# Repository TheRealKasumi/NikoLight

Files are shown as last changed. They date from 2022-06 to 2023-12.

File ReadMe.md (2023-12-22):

# NikoLight






## Disclaimer for Hardware 2.2

Currently I am rewriting the firmware from scratch including many improvements and new features.
The release was planned for Christmas 2023.
Even when many parts of the new firmware are already working, I am currently a little time limited and will not be able to finish it in time.
Instead, I added experimental support for the v2.2 hardware to the current firmware.
This does not come with all the new software and hardware features but it allows you to use the new (2.2) NikoLight boards with a significantly higher power output and the overall improved hardware.

The hardware version can be adjusted in the [SystemConfiguration.h](./mcu/include/configuration/SystemConfiguration.h).
Again, keep in mind that this experimental and there might be some hidden issues.

## Introduction

NikoLight is an open source ambient light that you can build yourself.
The project is primarily aimed at people who are not looking for a ready-made solution and prefer to tinker, modify, extend and work on it as a community.
As the name suggests, the project was started primarily for Tesla vehicles.
The focus is on the Model 3 and Model Y.
However, it can also be used for other cars with some small modifications.

With NikoLight you can control up to 8 zones with a variable number of WS2812-type LEDs.
For example, the 4 doors, the center console, the footwell lights and a light bar under the dashboard.
In total, several hundred LEDs can be controlled individually.

Since there should be an easy way to control all these LEDs, there are many different effects for each zone.
These can display a simple color, color gradients or even animations in the individual zones.
Since the controller has a motion sensor, some effects are even interactive.
The effects are expandable in the future and can be adapted to your wishes over time.
Even fully customized animation are possible.
You can create these on your computer and play them back in the car.

NikoLight can be easily integrated into your Tesla (and other cars).
There is a sensor that can be connected to the lighting around the footwell.
This way, NikoLight switches on and off automatically when you open or lock the car.
It is also possible to regulate the brightness together with the factory-installed lights or via the display.
The controller is also expandable and could support additional hardware in the future.
For example, there could be a CAN adapter to get more information from the vehicle.
How relevant these extensions will be, depends a little bit on the community and the support I will receive.

Once built and installed, NikoLight can be configured via a browser-based UI.
When starting the controller, a Wi-Fi hotspot is created, which you can connect to with any device.
The user interface can be accessed via a normal browser thanks to the integrated web server.
The project is therefore mostly platform-independent.

**Here is a short summary of the currently most interesting features:**

- Individual control of each LED installed in the car
- Hundreds of LEDs are possible
- Compatible with all WS2812-type LEDs (and LEDs with the same protocol)
- Fiber cables, light bars and normal LED strips are supported
- Up to 8 individual zones
- Currently 18 different effects that can be selected and further customized for each zone
- Browser based user interface
- Switching on/off as well as dynamic brightness via the existing lighting in the footwell
- Rotation and acceleration sensors
- Interactive effects
- Light shows
- Fully customized animations can be created on your PC (playback of fseq 1.0 files from [xLights](https://xlights.org/))
- OTA (wireless) updates
- Hardware is upgradeable via extensions in the future

## Some Videos and Pictures

NikoLight Demo 2 (https://www.youtube.com/watch?v=_N5h1IViB-E)

(click to watch on YouTube)

NikoLight Demo 1 (https://www.youtube.com/watch?v=bwzbVkCsNws)

(click to watch on YouTube)

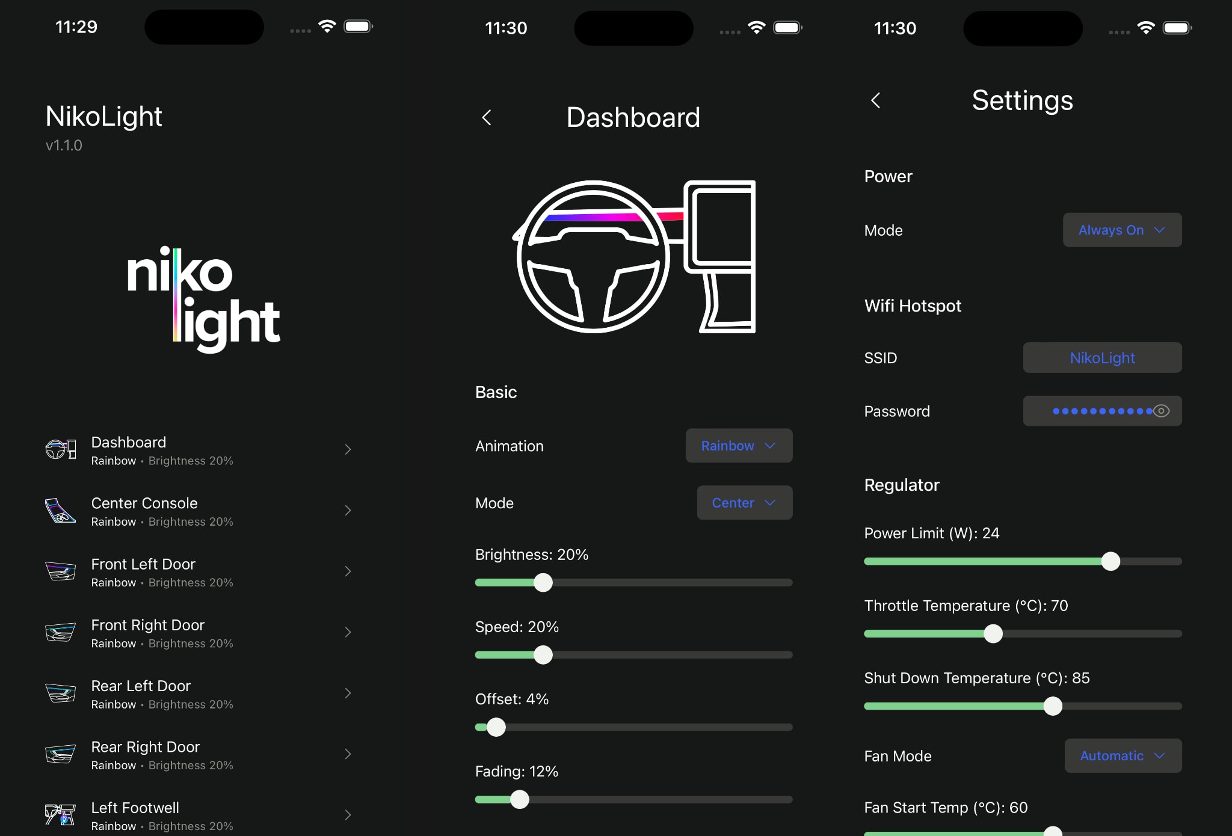
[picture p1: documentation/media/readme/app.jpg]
App


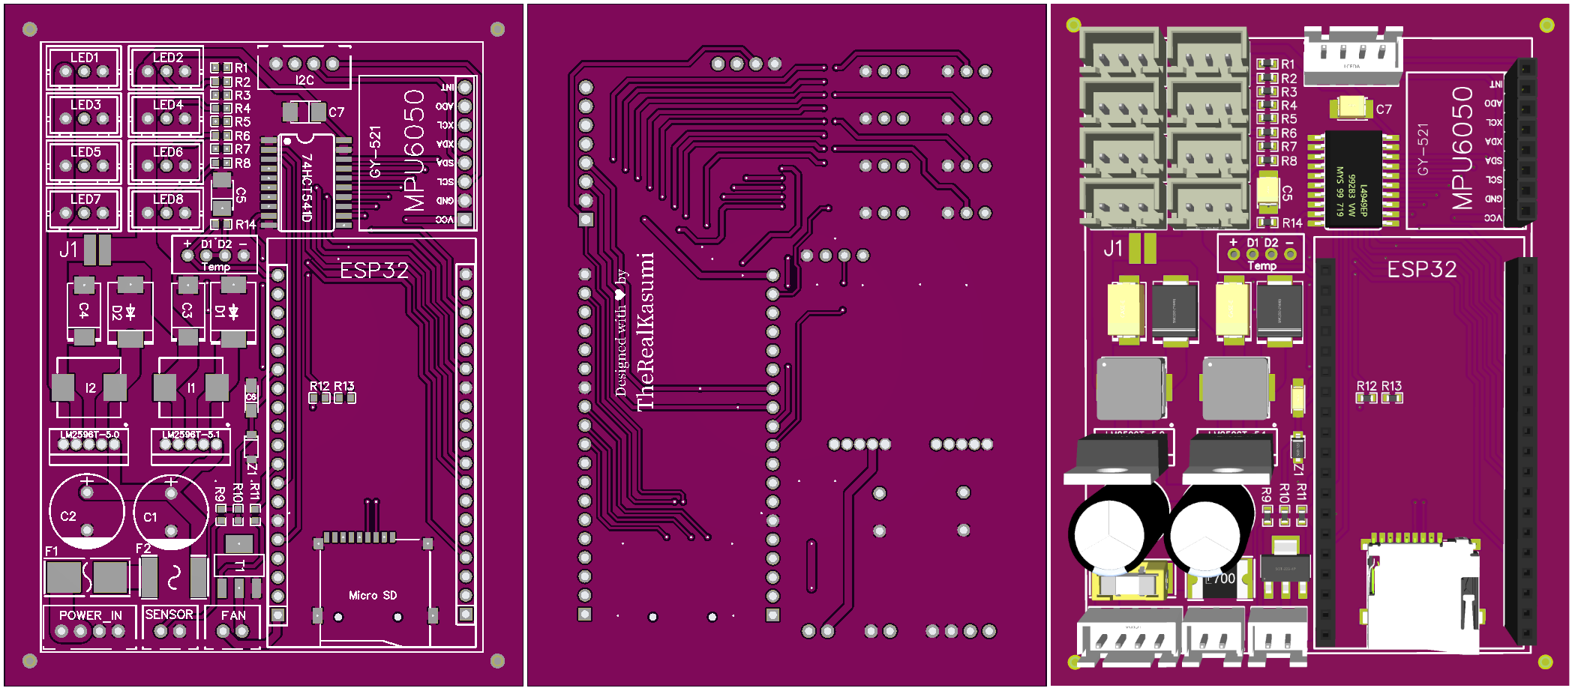
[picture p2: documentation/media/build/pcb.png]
PCB


## Planning

It is recommended to read the [planning](documentation/planning.md) document before you start the project.
There are some important considerations and decisions you have to make first.
This will save you some trouble and makes it easier to buy the right parts.

## Part List

A list of required and optional parts can be found [here](documentation/part-list.md).

## Build Guide

The build guide can be found [here](documentation/build.md).

## One Request

A lot of our time, effort and money went into this project.
Nevertheless, we share it publicly with you.
You can use it for free, modify it and even earn a coffee by building the parts for other people as long as you are a private person without commercial intentions.
But please **don't steal** our work, be a little **respectful** and **give credits**.
That said, I hope you have a lot of fun and great experience with NikoLight!
Thank you💖!

## Contributors

<table>
	<tbody>
		<tr>
			<td align="center" valign="top" width="200px">
        <br />
				<a href="https://github.com/TheRealKasumi">
					TheRealKasumi
					<br />
					<b>TheRealKasumi</b>
				</a>
				<hr />
				<p style="text-align: left">
					<a href="https://github.com/TheRealKasumi/NikoLight/issues?q=author%3ATheRealKasumi">🐛 bug</a><br />
					<a href="https://github.com/TheRealKasumi/NikoLight/commits?author=TheRealKasumi">💻 code</a><br />
					🖋 content<br />
					<a href="https://github.com/TheRealKasumi/NikoLight/commits?author=TheRealKasumi">📖 doc</a><br />
					<a href="https://github.com/TheRealKasumi/NikoLight/tree/main/ui">🎨 design</a><br />
					💡 example<br />
					🤔 ideas<br />
					<a href="https://github.com/TheRealKasumi/NikoLight/tree/main/.github">🚇 infra</a><br />
					<a href="https://github.com/TheRealKasumi/NikoLight/commits?author=TheRealKasumi">🚧 maintenance</a><br />
					<a href="https://github.com/TheRealKasumi/NikoLight">🧑‍🏫 mentoring</a><br />
					<a href="https://github.com/TheRealKasumi/NikoLight/commits?author=TheRealKasumi">📦 platform</a><br />
					<a href="https://github.com/TheRealKasumi/NikoLight">🔌 plugin</a><br />
					📆 projectManagement<br />
					📣 promotion<br />
					💬 question<br />
					🔬 research<br />
					<a href="https://github.com/TheRealKasumi/NikoLight/pulls?q=is%3Apr+reviewed-by%3ATheRealKasumi">👀 review</a><br />
					🛡️ security<br />
					<a href="https://github.com/TheRealKasumi/NikoLight">🔧 tool</a><br />
					<a href="https://github.com/TheRealKasumi/NikoLight/commits?author=TheRealKasumi">⚠️ test</a><br />
					<a href="https://github.com/TheRealKasumi/NikoLight/blob/main/documentation/build.md">✅ tutorial</a><br />
					<a href="https://www.youtube.com/watch?v=_N5h1IViB-E">📹 video</a><br />
				</p>
			</td>
			<td align="center" valign="top" width="200px">
        <br />
				<a href="https://github.com/danielbayerlein">
					danielbayerlein
					<br />
					<b>danielbayerlein</b>
				</a>
				<hr />
				<p style="text-align: left">
					<a href="https://github.com/TheRealKasumi/NikoLight/issues?q=author%3Adanielbayerlein">🐛 bug</a><br />
					<a href="https://github.com/TheRealKasumi/NikoLight/commits?author=danielbayerlein">💻 code</a><br />
					<a href="https://github.com/TheRealKasumi/NikoLight/tree/main/ui">🎨 design</a><br />
					🤔 ideas<br />
					<a href="https://github.com/TheRealKasumi/NikoLight/tree/main/.github">🚇 infra</a><br />
					<a href="https://github.com/TheRealKasumi/NikoLight/commits?author=danielbayerlein">🚧 maintenance</a><br />
					📆 projectManagement<br />
					💬 question<br />
					<a href="https://github.com/TheRealKasumi/NikoLight/pulls?q=is%3Apr+reviewed-by%3Adanielbayerlein">👀 review</a
					><br />
					<a href="https://github.com/TheRealKasumi/NikoLight/tree/main/ui/public/locales">🌍 translation</a><br />
					<a href="https://github.com/TheRealKasumi/NikoLight/commits?author=danielbayerlein">⚠️ test</a><br />
				</p>
			</td>
			<td align="center" valign="top" width="200px">
        <br />
				<a href="https://github.com/JakobLichterfeld">
					JakobLichterfeld
					<br />
					<b>JakobLichterfeld</b>
				</a>
				<hr />
				<p style="text-align: left">
					<a href="https://github.com/TheRealKasumi/NikoLight/issues?q=author%3AJakobLichterfeld">🐛 bug</a><br />
					<a href="https://github.com/TheRealKasumi/NikoLight/commits?author=JakobLichterfeld">💻 code</a><br />
					<a href="https://github.com/TheRealKasumi/NikoLight/commits?author=JakobLichterfeld">📖 doc</a><br />
					🤔 ideas<br />
					<a href="https://github.com/TheRealKasumi/NikoLight/tree/main/.github">🚇 infra</a><br />
					<a href="https://github.com/TheRealKasumi/NikoLight/commits?author=JakobLichterfeld">🚧 maintenance</a><br />
					<a href="https://github.com/TheRealKasumi/NikoLight">🧑‍🏫 mentoring</a><br />
					📆 projectManagement<br />
					💬 question<br />
					<a href="https://github.com/TheRealKasumi/NikoLight/pulls?q=is%3Apr+reviewed-by%3AJakobLichterfeld">👀 review</a><br />
					<a href="https://github.com/TheRealKasumi/NikoLight/commits?author=JakobLichterfeld">⚠️ test</a><br />
					<a href="https://github.com/TheRealKasumi/NikoLight/blob/main/documentation/build.md">✅ tutorial</a><br />
				</p>
			</td>
			<td align="center" valign="top" width="200px">
        <br />
				<a href="https://github.com/heyitsmarlon">
					heyitsmarlon
					<br />
					<b>heyitsmarlon</b>
				</a>
				<hr />
				<p style="text-align: left">
					<a href="https://github.com/TheRealKasumi/NikoLight/commit/0f9c097bd0b3cda26543b43a7343aa3b4d4c56f0">📖 doc</a><br />
				</p>
			</td>
			<td align="center" valign="top" width="200px">
        <br />
				<a href="https://github.com/MathiasSeifert">
					MathiasSeifert
					<br />
					<b>MathiasSeifert</b>
				</a>
				<hr />
				<p style="text-align: left">
					<a href="https://github.com/TheRealKasumi/NikoLight/commits?author=MathiasSeifert">📖 doc</a><br />
				</p>
			</td>
      </tr>
      <tr>
			<td align="center" valign="top" width="200px">
        <br />
				<a href="https://github.com/PhilippDenn">
					PhilippDenn
					<br />
					<b>PhilippDenn</b>
				</a>
				<hr />
				<p style="text-align: left">
					<a href="https://github.com/TheRealKasumi/NikoLight/issues?q=author%3APhilippDenn">🐛 bug</a><br />
					🤔 ideas<br />
				</p>
			</td>
			<td align="center" valign="top" width="200px">
        <br />
				<a href="https://github.com/rgrae81">
					rgrae81
					<br />
					<b>rgrae81</b>
				</a>
				<hr />
				<p style="text-align: left">
					<a href="https://github.com/TheRealKasumi/NikoLight/tree/main/model">🎨 design</a><br />
				</p>
			</td>
      <td align="center" valign="top" width="200px"></td>
      <td align="center" valign="top" width="200px"></td>
      <td align="center" valign="top" width="200px"></td>
		</tr>
	</tbody>
</table>

## Disclaimer

Please be careful when working on the project and especially your car.
I am not a professional electrical engineer and only doing this as a hobby on the side.
Use this project at your own risk.

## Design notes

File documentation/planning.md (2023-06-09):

# Planning

It is recommended to read through this short document before you start the project.
There are some important considerations and decisions you need to make first.
This will save you some trouble and make it easier to buy the right parts.
It will also help when building the project later.

## LED Configuration

The LED configuration is the most important planning step.
Here you need to consider which LEDs you want to use in which place, how they are attached, the number you want to install in your car and how to wire them.
This is personal preference and will influence the part list and building steps.
Also, it will affect how much work you have to put into the project.
So let's start with some important information that hopefully will answer some of your questions and help you with the planning.

### NikoLight, Channels, Zones and LEDs

Alright, let's start with first thing first.
NikoLight currently has a total of **8 LED channels**.
These channels are for the individual zones in your car.
This means that there are **8 different zones** that can be controlled independently.
How you spread them in your car is completely up to you.
You also don't have to use all of them, but you can if you want to.
An example could look like this:

| Channel/Zone | Used for |
| --- | --- |
| 1 | Dashboard |
| 2 | Center console |
| 3 | Left, front door |
| 4 | Right, front door |
| 5 | Rear, left door |
| 6 | Rear, right door |
| 7 | Footwell lighting 1 |
| 8 | Footwell lighting 2 |

NikoLight is using digital LEDs, so that it control each LED individually.
The LED type used is **WS2812** and all LEDs accepting the same protocol at a 5V input.
Other LED types might not work as expected.

Each zone can have a **variable number of LEDs**.
This number can reach from **0 up to a few hundreds**.
The limiting factors for this are: available memory, time required for data transmission and processing power of the microcontroller. In practice this means a zone should not have more than 200 LEDs.

Every single LED in a zone is **addressable**.
This means that NikoLight can "talk" to the individual LEDs and set a 24 bit color value for each.
You can compare this to the pixels of your monitor.
This is achieved by **chaining the LEDs**, like it is done on LED strips.
So each LED per zone will get a number from 0 to n, where n is the last LED in the line.

LED Chain

### Luminant Types

Currently there are three different types of luminants available that you can choose from. They are all fully supported by NikoLight, but not each luminant is suitable for each installation location.

#### Basic WS2812 LED strip

This is the most widely availble type of luminant - a series of WS2812 LEDs mounted in series on a thin, flexible PCB strip.
These strips are available in various lenghts, widths and density (count of LEDs per meter).
Possible installation locations for the LED strip are the dashboard and the foot wells.
A density of around 60 LEDs/meter is a good compromise between cost/power consumption and good looking light (effects).

##### Advantages

* easy to obtain in various configurations
* supports all light effects since many LEDs are distributed across the strip

##### Disadvantages

* can only be installed in locations where it is not directly visible

#### Fiber tube with WS2812 LEDs as light injectors

This type of luminant is a small flexible tube with a tab on it's side. WS2812 LEDs can be placed on one or (better) both ends of the tube to inject light into the tube and make it glow (fairly) evenly along its entire length.
The fiber tube is suitable for all installation locations in the Tesla Model 3/Y with the exception of the footwell lighting. As of now it is also the only lumimant that can be installed in the 2021 or later center console of Model 3/Y and around the seats.

##### Advantages of fiber tube

* low cost
* low power consumption
* easy, flexible installation

##### Disadvantages of fiber tube

* you can have at most 2 colors per tube segment, one injected from each side, which greatly limits the effects that you can display with it
* because of it's white(-ish) color the fiber tube visually stands out a bit againts the dark interior in daylight which can look less professional depending on your taste

#### Light bar with WS2812 LEDs

The light bar is like a hybrid of the light strip and fiber tube. It consists of a very thin WS2812 LED strip mounted onto an also very thin and flexible light distribution bar that is additionally covered in a black, translucent tape.
The density of the currently available light bars is very high with around 130 LEDs/meter. Possible installation locations are the dashboard, the door panels and the pre-2021 center console.

##### Advantages of light bar

* can be installed almost anywhere in the care, where a fiber tube can be installed as well
* supports all light effects since many LEDs are distributed across the light bar
* not very visible in daylight when turned off because it is wrapped in black tape

##### Disadvantages of light bar

* more expensive
* not as easy to obtain because there are not many shops that carry it (especially in Europe)
* only available in lengths up to 1 meter (but you can extend it by soldering 2 bars together)
* consumes a lot of power because of the high LED count
* can also not extend it very far beyond 1 meter before hitting the recommended 200 LED/channel limit

#### Recommendation

The recommendation is to use a normal LED strip under the dashboard for ease of installation, cost and power consumption.
As an alternative it is also possible to use a light bar for the dashboard as well, but it requires extra effort to solder two light bars together to achieved the required length.
For the 2021 and later models use of a light bar in the dashboard and upper door panels results in a nice continuous line of light from door to door.

The fiber tubes are working well for the center console or around the seats.

For the doors, the light bars turned out to be very nice looking and be less noticeable when turned off.
The choice here is fully up to you.
All parts can be found on the [part list](part-list.md).

### Zones

As explained above, NikoLight supports up to **8 different zones**.
How you select these zones is up to you, but keep in mind that you must be able to install and wire the LEDs in the zones.

Since NikoLight was designed with the Tesla Model 3 and Model Y in mind, there is a recommended configuration of the zones.
This is the same configuration as shown in the following video (click to open).

NikoLight Demo (https://www.youtube.com/watch?v=_N5h1IViB-E)

The following table assumes that the NikoLight controller is placed below the center console for easy access and wiring. (It would be best if the antenna of the ESP32 points to the front and the USB port to the back of the vehicle. This way we ensure consistent acceleration directions from the sensor for all users.)

| Zone | LEDs | Type | Cable Length | Physical Channel |
| --- | ---- | --- | --- | --- |
| Dash | 72 | LED strip | 100 cm | 1 |
| Center Console | 4 | Fiber cable and injectors | 150 cm | 2 |
| Front Doors | 130  | Light bar (2 in parallel) | 215 cm + 50 cm | 3, 4 |
| Rear Doors | 92 | Light bar | 405 cm + 45 cm | 5, 6 |
| Footwell lighting | 4 | LED strip or single LEDs  | 100 cm | 7, 8 |

So for this build we have a total of around 784 LEDs and need ~20 m cable with 3 wires.
Also, ~2.5 m of fibre cable is recommended for use around the centre console.
Make sure to measure the required lengths carefully for individual build.

### Recommended length of light bars

If you are using the light bars, these are the recommended length of the light bars:
| Location | length of light bars |
| --- | --- |
| Front Doors top (MY 2019) | 100 cm, and shorten about 10 cm  |
|  Rear Doors top | 75 cm, and shorten a bit  |
| Front and Rear Doors around handle | 100 cm  |
| Dashboard | 130 cm, connect 2* 75 cm in series and shorten a bit  |
| Center console MY2019 (with cover above mobile phone holder) | 2* 85 cm (100 cm, and shorten about 15 cm) |
| Center console MY2021 | Fibre Wire, tbd light bar |

Make sure to measure the required lengths carefully for individual build.

## Power Consumption

Since this project can make use of many LEDs, the power consumption plays an important role.
NikoLight can (and should) be built with an onboard regulator.
This ensures that you stay below the limits the hardware can handle without modifications.
The regulator has 2 channels and is capable of providing a total of 6 A at 5 V, which is around 30 W of power.
These 6A are split to 2x 3A on the channels {1, 3, 5, 7} and {2, 4, 6, 8}.
The load of the two single channels should not exceed 3 A or 15 W at maximum.
By default, NikoLight has a configured power limit of 20 W, or 10 W per regulator.
If this limit is reached, the brightness is reduced to stay below this limit.
Also, a temperature limit of 80 °C is enforced by default when the optional temperature sensors are installed.

If you need to save some money, you can also only build one channel of the regulator.
Then the power output is halved and the jumper `J1` must be closed.
The full dual channel build is recommended because otherwise you are very limited on brightness.

If more power is really needed, then an external regulator is required and the board's input must be bypassed.
In that case, all components for the onboard regulator should be removed from the board.
An exception are the capacitors `C3` and `C4`, which should remain on the board.
The jumper `J1` should be closed
Instead of powering the board via the power input, it must be powered via an LED output.
Make sure to provide stable 5V to an LED output.

However, be careful when dealing with the high currents an external regulator could provide.
It could significantly heat up your connectors, wires, LEDs or even the NikoLight board.
You might need to change the connectors, use thicker wires and thicker copper on the PCB.

Assuming "average" WS2812 LED chips, each channel can draw around 14 mA at 5 V and maximum brightness.
Since each LED has 3 channels (red, green, blue), a current draw of around 42 mA has to be assumed.
To calculate the total power draw, the following formula can be used:

`power = led_count x 0.042 x 5`

From the example configuration above, we assume a total number of 784 LEDs.
You probably already feel that this could easily exceed the limits of the voltage regulator NikoLight comes with.

In theory, we could reach a current of 33 A (784 x 0.042) or 165 W (784 x 0.042 x 5) of power.
This is not safe to deal with for everyone.
Also, it would allow for brightness levels, that are far from practical, especially for the light bars.

In a normal use case, the power provided by the NikoLight controller is enough.
It still allows for a decent brightness without having to deal with dangerously high currents.
Like mentioned above, by default the software ensures that a maximum power draw of around 20 W is not exceeded.
Also, the regulator temperature is limited to 80 °C when the optional temperature sensors are installed.
You can adjust these limits in the UI.
For the power limit calculation to work properly, the LED voltage and current per channel must be configured correctly.

> What happens when I exceed the power limit of the regulator temporary or permanently?

Generally it is NOT recommended to do so in any way.
The 20 W power limit, or 10 W per channel, was tested to be a good compromise between brightness and regulator temperature.
Installing the optional temperature sensors to the board will also limit the temperature to 80 °C by default.
This temperature can be exceeded without the sensors.
When using a proper LM2596 (not faked ones), it will shut down as soon as a critical current or temperature (115 °C) is reached.
No damage _should_ be taken from this.
However, don't cry at me when you burn something down.
You have been warned.

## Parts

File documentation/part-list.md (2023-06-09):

# Part List

This document contains the full list of all parts to build NikoLight.
The list has been split into required and optional parts.
Since NikoLight can be modified in a lot of ways, the actual part list depends a little on your individual plans.
Make sure to read the [planning](planning.md) document first.
Also, this list assumes that you have all necessary tools and materials for building electronics projects, like a soldering iron.

## Assembled PCB by JLCPCB

Most parts will come fully assembled with the board.
The parts are already contained in the fiels for the board.
You only have to insert the ESP32 board and the MPU6050 manually.

| Part | Count | Source | Comment |
| --- | ----- | --- | --- |
| NikoLight PCB (SMT Service) | 1 | [JLCPCB][jlcpcb] | Can be ordered from JLCPCB using board files from the project |
| NikoLight Case | 1 | [JLCPCB][jlcpcb] | Can be ordered from JLCPCB using 3D models from the project |
| AzDelivery ESP32 Dev Board | 1 | [Amazon][esp32] | Or compatible with same size and layout |
| MPU6050 Motion Sensor | 1 | [Reichelt][mpu6050] | Works without but is highly recommended |
| JST-XH 2 Pin Male | 2 | [Reichelt][jstxh2m] | |
| JST-XH 3 Pin Male | 8 | [Reichelt][jstxh3m] | |
| JST-XH 4 Pin Male | 2 | [Reichelt][jstxh4m] | |
| JST-XH Connectors | 36 | [Reichelt][jstxhconn] | Maybe get a few more to be on the safe side |

## Self Assembly

| Part | Count | Source | Comment |
| --- | ----- | --- | --- |
| NikoLight PCB | 1 | [JLCPCB][jlcpcb] | Can be ordered from JLCPCB using board files from the project |
| NikoLight Case | 1 | [JLCPCB][jlcpcb] | Can be ordered from JLCPCB using 3D models from the project |
| AzDelivery ESP32 Dev Board | 1 | [Amazon][esp32] | Or compatible with same size and layout |
| MPU6050 Motion Sensor | 1 | [Reichelt][mpu6050] | Works without but is highly recommended |
| Micro SD Socket | 1 | [Amazon][sdsocket] | |
| 74HCT541D | 1 | [Reichelt][74hct541d] | |
| LM2596T-5.0 Regulator. | 1/2 | [Reichelt][lm2596] | Make sure to get the fixed 5V version |
| Inductor min. 33µH | 1/2 | [Reichelt][ind33] | |
| IN5824 Schottky Diode | 1/2 | [Reichelt][in5824] | |
| Capacitor 680µf | 1/2 | [Reichelt][cap680] | |
| SMD Capacitor 10µf 10V | 1 | [Reichelt][cap10] | |
| SMD Capacitor 100µf 10V | 3 | [Reichelt][cap100] | |
| SMD Capacitor 220µf 10V | 2 | [Reichelt][cap220] | |
| SMD Resistor 220Ω 125mW | 9 | [Reichelt][res220] | |
| SMD Resistor 1kΩ 125mW | 1 | ??? | |
| SMD Resistor 4.7kΩ 125mW | 1 | [Reichelt][res4700] | |
| SMD Resistor 2.2kΩ 125mW | 2 | [Reichelt][res2200] | |
| SMD Resistor 6.65Ω 500mW | 1 | [JCSC][res6] | |
| SMD Transistor 1A 60V | 1 | [Reichelt][tra1a60v]  | |
| Zener Diode 3.0V | 1 | [Reichelt][zener3.0]  | |
| Fuse and Holder 5A | 2 | [Reichelt][fuse] | |
| Poly Fuse 3A | 1 | [Reichelt][pfuse] | |
| JST-XH 2 Pin Male | 2 | [Reichelt][jstxh2m] | |
| JST-XH 2 Pin Female | 2 | [Reichelt][jstxh2f] | |
| JST-XH 3 Pin Male | 8 | [Reichelt][jstxh3m] | |
| JST-XH 3 Pin Female | 8 | [Reichelt][jstxh3f] | |
| JST-XH 4 Pin Male | 2 | [Reichelt][jstxh4m] | |
| JST-XH 4 Pin Female | 2 | [Reichelt][jstxh4f] | |
| JST-XH Connectors | 36 | [Reichelt][jstxhconn] | Maybe get a few more to be on the safe side |

## Possible LEDs

| Part | Source | Comment |
| --- | --- | --- |
| WS2812 LED Strip  | [Amazon][ws2812b] | |
| Fiber Tube | [Amazon][fiber] | |
| LED Injector Case | [JLCPCB][jlcpcb]  | Can be ordered here using 3D models from the project |
| LED Light Bars | [IYC][lightbars]  | 30 cm/75 cm/100 cm |
| LED Light Bars Alternative | [Herwins][lightbars_symphony]  | 25 cm/75 cm/100 cm (Symphony version are WS2812, check polarity before use, see [build](build.md). These are very small and are masked with black foil and are thus dimmed, which is great as we can use the full color spectrum of the LEDs and at the same time do not get blind while driving.) |

## Optional Parts

| Part | Count | Source | Comment |
| --- | --- | --- | --- |
| Heatsink for Regulators | 2 | [Reichelt][hsink]  | Helps to keep the temperature a little lower |
| Temperature Sensors | 2 | [Reichelt][tsense] | Not required but a safety feature |
| Cooling Fan 30x30 | 1 | [Reichelt][fan] | Not required but nice to have |
| Shrinking tube | depends | [Amazon][tubes] | Will help you to have a cleaner and safer build |
| Fabric tape | depends | [Amazon][tape] | Will help you to have a cleaner and safer build |
| 3 wire cable | depends | [Amazon][3-wire-cable] | you can use this 3 wire cable to connect the LEDs |

### How to get the signal of the factory build footwell lights without any harm

| Part | Count | Source | Comment |
| --- | --- | --- | --- |
| electricity thief/T-Connector | 2/1 | [Amazon][T-connector] | to get the car signal |
| Female Connector  | 1 | [Mouser][female-connector] | TE Connectivity / AMP P/N: 1534111-1, car side uses this |
| Male Connector | 1 | [Mouser][memale-connector] | TE Connectivity / AMP P/N: 1-1534155-1, factory build footwell LED’s use this |
| Retainer / Cover for Connectors | 2 |  [Mouser][retainer] | TE Connectivity / AMP P/N: 1534027-1, each connector needs one |
| Pin Connectors | 4 | [Mouser][pin-connectors] | TE Connectivity / AMP P/N: 1-928918-1 (Cut Strip), 2 per plug |

[jlcpcb]: https://cart.jlcpcb.com/quote?orderType=1&stencilLayer=2&stencilWidth=100&stencilLength=100
[esp32]: https://www.amazon.de/AZDelivery-NodeMCU-Development-Nachfolgermodell-ESP8266/dp/B071P98VTG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
[mpu6050]: https://www.reichelt.de/entwicklerboards-beschleunigung-gyroskop-3-achsen-mpu-6050-debo-sens-3axis-p253987.html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
[jstxh2m]: https://www.reichelt.de/jst-buchsengehaeuse-1x2-polig-xh-jst-xh2p-bu-p185085.html?&trstct=pos_0&nbc=1
[jstxh2f]: https://www.reichelt.de/jst-stiftleiste-gerade-1x2-polig-xh-jst-xh2p-st-p185073.html?&trstct=pos_0&nbc=1
[jstxh3m]: https://www.reichelt.de/jst-buchsengehaeuse-1x3-polig-xh-jst-xh3p-bu-p185086.html?&trstct=pos_6&nbc=1
[jstxh3f]: https://www.reichelt.de/jst-stiftleiste-gerade-1x3-polig-xh-jst-xh3p-st-p185074.html?&trstct=pos_1&nbc=1
[jstxh4m]: https://www.reichelt.de/jst-buchsengehaeuse-1x4-polig-xh-jst-xh4p-bu-p185087.html?&trstct=pos_5&nbc=1
[jstxh4f]: https://www.reichelt.de/jst-stiftleiste-gerade-1x4-polig-xh-jst-xh4p-st-p185075.html?&trstct=pos_13&nbc=1
[jstxhconn]: https://www.reichelt.de/jst-crimpkontakt-buchse-xh-jst-xh-ckb-p185091.html?&trstct=pos_0&nbc=1
[sdsocket]: https://www.amazon.de/sourcingmap-St%C3%BCck-Oberfl%C3%A4chenmontage-Speicherkarte-Sockel/dp/B00E6PVMU2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
[74hct541d]: https://www.reichelt.de/latch-octal-4-5--5-5-v-so-20-74hct-541d-nxp-p216688.html?&trstct=pos_0&nbc=1
[lm2596]: https://www.reichelt.de/abwaerts-schaltregler-adj-4-5--40-v-5-0-v-3-a-to-220-5-lm-2596-t5-0-p109365.html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
[ind33]: https://www.reichelt.de/smd-power-induktivitaet-eisenpulverkern-100-h-pan-etqp5m101ygk-p245793.html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
[in5824]: https://www.reichelt.de/schottkydiode-40-v-5-a-do-214ab-smc-sk-54c-p146598.html?&trstct=pos_3&nbc=1
[cap680]: https://www.reichelt.de/elko-radial-680-uf-25-v-105-c-low-esr-fm-a-680u-25-p200061.html?&trstct=pos_6&nbc=1
[cap10]: https://www.reichelt.de/smd-tantal-kondensator-10-f-10v-tps-3216-10-10-p167046.html?&trstct=pos_1&nbc=1
[cap100]: https://www.reichelt.de/smd-tantal-100-f-10v-125-c-t491c-100u-10-p206478.html?&trstct=pos_0&nbc=1
[cap220]: https://www.reichelt.de/smd-tantal-220-uf-10-v-2000-h-posc-220-10d-40-p145946.html?&trstct=pos_0&nbc=1
[res220]: https://www.reichelt.de/smd-widerstand-0805-220-ohm-125-mw-1--smd-0805-220-p32878.html?&trstct=pos_1&nbc=1
[res4700]: https://www.reichelt.de/smd-widerstand-0805-4-7-kohm-125-mw-1--smd-0805-4-70k-p32894.html?&trstct=pos_6&nbc=1
[res2200]: https://www.reichelt.de/smd-widerstand-0805-2-2-kohm-125-mw-1--smd-0805-2-20k-p32890.html?&trstct=pos_13&nbc=1
[res6]: https://lcsc.com/product-detail/Chip-Resistor-Surface-Mount_YAGEO-RC1210FR-076R65L_C309592.html
[tra1a60v]: https://www.reichelt.de/bipolartransistor-npn-60v-1a-hfe-100--250-sot-223-bcp-55-16-smd-p41326.html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
[zener3.0]: https://www.reichelt.de/zenerdiode-3-3-v-300mw-sod-323-mm3z3v3t1g-ons-p219513.html?&trstct=pos_0&nbc=1
[fuse]: https://www.reichelt.de/smd-sicherungshalter-mit-sicherung-5-0-a-125-v-superflink-litt-0154005-dr-p229204.html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
[pfuse]: https://www.reichelt.de/rueckstellende-sicherungen-8-a-litt-ruef400-p242414.html?&trstct=pos_0&nbc=1
[ws2812b]: https://www.amazon.de/BTF-LIGHTING-adressierbar-Vollfarbiger-wasserdichte-DIY-Projekte/dp/B088BRY2SH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
[fiber]: https://www.amazon.de/TABEN-Autoseitenlicht-LED-Beleuchtung-Innenatmosph%C3%A4re-Neonstreifenleuchten/dp/B08DLJ2JJ1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
[lightbars]: https://individualiseyourcar.com/en/ambitrim-digital-rgb-rgbic-full-led-ambient-light-components.html
[lightbars_symphony]: https://de.aliexpress.com/item/1005004297563628.html
[hsink]: https://www.reichelt.de/kuehlkoerper-15-2-mm-alu-26-k-w-to-220-fk-242-sa-220-o-p228044.html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
[tsense]: https://www.reichelt.de/digital-thermometer-1-wire--0-5-c-to-92-ds-18b20-p58169.html?&trstct=pos_0&nbc=1
[fan]: https://www.amazon.de/gp/product/B071JN6HKM/ref=ppx_yo_dt_b_asin_title_o08_s00?ie=UTF8&psc=1
[tubes]: https://www.amazon.de/ChiliTec-12000058-Chilitec-Schrumpfschlauch-Sortiment-100-teilig/dp/B003H9CJ1Y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
[tape]: https://www.amazon.de/tesa-Gewebeband-Witterungsbest%C3%A4ndiges-Panzertape-Befestigen/dp/B000KT7E0U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
[3-wire-cable]: https://www.amazon.de/dp/B0999BVQYL
[T-connector]: https://www.amazon.de/dp/B07F3SGJXR
[female-connector]: https://www.mouser.com/ProductDetail/TE-Connectivity-AMP/1534111-1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
[memale-connector]: https://www.mouser.com/ProductDetail/571-1-1534155-1
[retainer]: https://www.mouser.com/ProductDetail/571-1534027-1
[pin-connectors]:https://www.mouser.com/ProductDetail/571-1-928918-1-CT

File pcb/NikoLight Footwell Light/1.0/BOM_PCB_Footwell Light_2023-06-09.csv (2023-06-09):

ID | Name | Designator | Footprint | Quantity | Manufacturer Part | Manufacturer | Supplier | Supplier Part | Price
1 | 100nF | C1,C2,C3,C4,C5 | C0402 | 5 | CL05B104KO5NNNC | SAMSUNG(三星) | LCSC | C1525 | 0.001
2 | WS2812B-MINI | LED1,LED2,LED3,LED4,LED5,LED6,LED7,LED8,LED9,LED10 | LED-SMD_4P-L3.5-W3.5-TL_WS2812B | 10 | WS2812B-Mini | worldsemi | LCSC | C527089 | 0.118

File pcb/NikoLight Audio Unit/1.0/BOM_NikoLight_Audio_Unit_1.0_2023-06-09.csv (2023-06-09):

ID | Name | Designator | Footprint | Quantity | Manufacturer Part | Manufacturer | Supplier | Supplier Part | Price
1 | 22.1K | R2 | R0402 | 1 | RC0402FR-0722K1L | YAGEO(国巨) | LCSC | C163478 | 0.001
2 | 2K | R5 | R0402 | 1 | RC0402FR-072KL | YAGEO(国巨) | LCSC | C60488 | 0.001
3 | 22uF | C10,C3 | CAP-SMD_L3.2-W1.6-RD | 2 | T491A226K006AT | KEMET(基美) | LCSC | C118989 | 0.084
4 | 10uF | C1,C2 | CASE-A_3216 | 2 | T491A106K010AT | KEMET(基美) | LCSC | C1508940 | 0.069
5 | 100nF | C5,C8,C9 | C0603 | 3 | 0603B104K500NT | FH(风华) | LCSC | C30926 | 0.002
6 | 1uF | C7 | C0603 | 1 | CL10A105KB8NNNC | SAMSUNG(三星) | LCSC | C15849 | 0.006
7 | 10uF | C6,C4 | CAP-SMD_L2.0-W1.2 | 2 | TAJR106K006RNJ | Kyocera AVX | LCSC | C132274 | 0.102
8 | LESD5D5.0CT1G | D1,D2,D3 | SOD-523_L1.2-W0.8-LS1.6-BI | 3 | LESD5D5.0CT1G | Leshan Radio | LCSC | C383211 | 0.015
9 | PMEG2010ER,115 | D5 | SOD-123_L2.6-W1.7-LS3.5-RD | 1 | PMEG2010ER,115 | Nexperia(安世) | LCSC | C82288 | 0.119
10 | ESP32-WROOM-32E(16MB) | ESP32 | WIFI-SMD_ESP32-WROOM-32E | 1 | ESP32-WROOM-32E-N16 | ESPRESSIF(乐鑫) | LCSC | C701343 | 4.731
11 | SZYY0805B | LED1 | LED0805-R-RD_BLUE | 1 | SZYY0805B | yongyu(永裕光电) | LCSC | C434433 | 0.013
12 | SS8050-G | Q1,Q2 | SOT-23-3_L2.9-W1.6-P1.90-LS2.8-BR | 2 | SS8050-G | CJ(江苏长电/长晶) | LCSC | C164886 | 0.02
13 | MMBT3904 | Q3,Q4,Q5 | SOT-23-3_L2.9-W1.6-P1.90-LS2.8-BR | 3 | MMBT3904 | Hottech(合科泰) | LCSC | C181119 | 0.007
14 | 47.5K | R3 | R0402 | 1 | RC0402FR-0747K5L | YAGEO(国巨) | LCSC | C137974 | 0.001
15 | 1kΩ | R10 | R0805 | 1 | 0805W8F1001T5E | UNI-ROYAL(厚声) | LCSC | C17513 | 0.002
16 | 680Ω | R11 | R0805 | 1 | 0805W8F6800T5E | UNI-ROYAL(厚声) | LCSC | C17798 | 0.002
17 | 330Ω | R12,R13,R14,R15,R22 | R0805 | 5 | 0805W8F3300T5E | UNI-ROYAL(厚声) | LCSC | C17630 | 0.002
18 | 4.7kΩ | R8,R9,R18,R19 | R1206 | 4 | 1206W4F4701T5E | UNI-ROYAL(厚声) | LCSC | C17936 | 0.003
19 | TS-1092S-B3D2-G | SW1,SW2 | SW-SMD_L6.1-W3.6-LS7.9 | 2 | TS-1092S-B3D2-G | Yuandi(元迪) | LCSC | C520860 | 0.049
20 | AMS1117-3.3 | U1 | SOT-223-3_L6.5-W3.4-P2.30-LS7.0-BR | 1 | AMS1117-3.3 | AMS | LCSC | C6186 | 0.146
21 | MICROXNJ | USB | MICRO-USB-SMD_MICROXNJ | 1 | MicroXNJ | SHOU HAN(首韩) | LCSC | C404969 | 0.034
22 | CP2102N-A02-GQFN28R | USB-UART | QFN-28_L5.0-W5.0-P0.50-TL-EP3.3 | 1 | CP2102N-A02-GQFN28R | SILICON LABS(芯科) | LCSC | C964632 | 1.721
23 | 10K | R1,R4,R16,R17,R6,R7 | R0402 | 6 | RC0402FR-0710KL | YAGEO(国巨) | LCSC | C60490 | 0.001
24 | 0154001.DR | F1 | FUSE-SMD_L9.8-W5.1 | 1 | 0154001.DR | Littelfuse(美国力特) | LCSC | C206908 | 1.33
25 | S4B-XH-A-1-(LF)(SN) | XH-DATA | CONN-TH_4P-P2.50_S4B-XH-A-1-LF-SN | 1 | S4B-XH-A-1(LF)(SN) | JST | LCSC | C163037 | 0.112
26 | S2B-XH-A-(LF)(SN) | XH-PWR | CONN-TH_S2B-XH-A-LF-SN | 1 | S2B-XH-A(LF)(SN) | JST | LCSC | C157931 | 0.058
27 | 4.7K | R20,R21 | R0402 | 2 | RC0402FR-074K7L | YAGEO(国巨) | LCSC | C105871 | 0.001
28 | PJ-327C-4A | AUDIOIN | AUDIO-SMD_PJ-327C-4A | 1 | PJ-327C-4A | HRO | LCSC | C145813 | 0.121
29 | SOD-123_L2.7-W1.6-LS3.7-RD | D7 | SOD-123_L2.7-W1.6-LS3.7-RD | 1 | MMSZ4684T1G | onsemi(安森美) | LCSC | C24672 | 0.046

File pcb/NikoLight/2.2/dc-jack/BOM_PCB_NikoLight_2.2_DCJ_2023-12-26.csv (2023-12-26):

ID | Name | Designator | Footprint | Quantity | Manufacturer Part | Manufacturer | Supplier | Supplier Part | Price
1 | R0402 | R19,R18 | R0402 | 2 | RC0402FR-071KL | YAGEO(国巨) | LCSC | C106235 | 0.001
2 | 10K | R37,R38,R11,R12,R13,R17,R29,R30,R31,R32 | R0402 | 10 | RC0402FR-0710KL | YAGEO(国巨) | LCSC | C60490 | 0.001
3 | 10uF | C31,C17,C20,C23 | CAP-SMD_L2.0-W1.2 | 4 | TAJR106K006RNJ | Kyocera AVX | LCSC | C132274 | 0.087
4 | B2B-XH-A (LF)(SN) | AIN,FAN | CONN-TH_B2B-XH-A-LF-SN | 2 | B2B-XH-A(LF)(SN) | JST | LCSC | C158012 | 0.033
5 | CR2032-BS-2-1 | B1 | BAT-TH_BS-2-1 | 1 | BS-2-1 | Q&J | LCSC | C70376 | 0.069
6 | 470uF | C1,C2 | CAP-SMD_BD10.0-L10.3-W10.3-LS11.0-R-RD | 2 | RVT1V471M1010 | ROQANG(容强) | LCSC | C72519 | 0.097
7 | 100nF | C3 | C0603 | 1 | CL10B104KB8NNNC | SAMSUNG(三星) | LCSC | C1591 | 0.003
8 | 100nF | C16,C18,C19 | C0603 | 3 | 0603B104K500NT | FH(风华) | LCSC | C30926 | 0.002
9 | 1uF | C4 | C0805 | 1 | CC0805KKX7R9BB105 | YAGEO(国巨) | LCSC | C91185 | 0.017
10 | 470pF | C5 | C0603 | 1 | CL10B471KB8NNNC | SAMSUNG(三星) | LCSC | C22396 | 0.006
11 | 33nF | C6 | C0603 | 1 | CL10B333KB8NNNC | SAMSUNG(三星) | LCSC | C21117 | 0.004
12 | 4.7uF | C7 | C1206 | 1 | CL31B475KBHNNNE | SAMSUNG(三星) | LCSC | C51205 | 0.032
13 | 1.8nF | C8 | C0402 | 1 | CL05B182KB5NNNC | SAMSUNG(三星) | LCSC | C5296 | 0.011
14 | 2.2nF | C9 | C0402 | 1 | CL05B222KB5NNNC | SAMSUNG(三星) | LCSC | C84703 | 0.004
15 | 100nF | C10,C21,C22,C24,C25,C26,C27,C28,C29 | C0402_NEW | 9 | CL05B104KO5NNNC | SAMSUNG(三星) | LCSC | C1525 | 0.001
16 | 100uF | C11,C12 | CAP-SMD_L7.3-W4.3-R-RD | 2 | T491D107K016AT | KEMET(基美) | LCSC | C110548 | 0.552
17 | 220uF | C13 | CASE-D_7343 | 1 | TAJD227K010RNJ | Kyocera AVX | LCSC | C8024 | 0.363
18 | 22uF | C14,C15 | CAP-SMD_L3.2-W1.6-RD | 2 | T491A226K006AT | KEMET(基美) | LCSC | C118989 | 0.087
19 | 100uF | C30 | CASE-B_3528 | 1 | T491B107K010AT | KEMET(基美) | LCSC | C122271 | 0.268
20 | TF-01A | MICRO_SD | TF-SMD_TF-01A | 1 | TF-01A | 韩国韩荣 | LCSC | C91145 | 0.175
21 | SS54_C22452 | D1 | SMA_L4.4-W2.8-LS5.4-R-RD | 1 | SS54 | MDD | LCSC | C22452 | 0.038
22 | SS34_C8678 | D2 | SMA_L4.3-W2.6-LS5.2-RD | 1 | SS34 | MDD | LCSC | C8678 | 0.023
23 | LESD5D5.0CT1G | D3,D4,D5 | SOD-523_L1.2-W0.8-LS1.6-BI | 3 | LESD5D5.0CT1G | Leshan Radio | LCSC | C383211 | 0.017
24 | PMEG2010ER,115 | D6 | SOD-123_L2.6-W1.7-LS3.5-RD | 1 | PMEG2010ER,115 | Nexperia(安世) | LCSC | C82288 | 0.109
25 | 1SMA4729AG | D7 | SMA_L4.4-W2.6-LS5.0-RD | 1 | 1SMA4729AG | SHIKUES(时科) | LCSC | C433396 | 0.025
26 | ESP32-WROOM-32E(16MB) | ESP32 | WIFI-SMD_ESP32-WROOM-32E | 1 | ESP32-WROOM-32E-N16 | ESPRESSIF(乐鑫) | LCSC | C701343 | 4.138
27 | 0154007.DR | F1 | FUSE-SMD_L10.0-W5.0 | 1 | 0154007.DR | Littelfuse(美国力特) | LCSC | C206918 | 1.566
28 | SMD2920P260TF/24 | F2 | F2920 | 1 | SMD2920P260TF/24 | PTTC(聚鼎) | LCSC | C209734 | 0.326
29 | XH-6A | I2C_1,I2C_2,I2C_3,I2C_4 | CONN-TH_6P-P2.50_XH-6A | 4 | XH-6A | BOOMELE(博穆精密) | LCSC | C5663 | 0.018
30 | 4.7uH | L1 | IND-SMD_L13.9-W12.6 | 1 | APS13A60M4R7 | Coilank(驰兴电感) | LCSC | C328260 | 0.589
31 | 68uH | L2 | IND-SMD_L12.3-W12.3_SMDRI127 | 1 | SMDRI127-680MT | SXN(顺翔诺) | LCSC | C9907 | 0.187
32 | B3B-XH-AM-(LF)(SN) | LED1,LED2,LED3,LED4,LED5,LED6,LED7,LED8 | CONN-TH_3P-P2.50_B3B-XH-AM-LF-SN | 8 | B3B-XH-AM(LF)(SN) | JST | LCSC | C161870 | 0.057
33 | SZYY0805B | PLED | LED0805-R-RD_BLUE | 1 | SZYY0805B | yongyu(永裕光电) | LCSC | C434433 | 0.013
34 | DC-5A | DC | DC-IN-TH_DC-005-5A-3.0 | 1 | DC-005-5A-3.0 | XKB Enterprise | LCSC | C388625 | 0.233
35 | SS8050-G | Q1,Q2 | SOT-23-3_L2.9-W1.6-P1.90-LS2.8-BR | 2 | SS8050-G | CJ(江苏长电/长晶) | LCSC | C164886 | 0.02
36 | BCP55-16,115 | Q3 | SOT-223-3_L6.5-W3.4-P2.30-LS7.0-BR | 1 | BCP55-16,115 | Nexperia(安世) | LCSC | C56551 | 0.086
37 | AMS1117-3.3 | U4 | SOT-223-3_L6.5-W3.4-P2.30-LS7.0-BR | 1 | AMS1117-3.3 | AMS | LCSC | C6186 | 0.141
38 | 3.3 | R1 | R0402 | 1 | AC0402FR-073R3L | YAGEO(国巨) | LCSC | C227057 | 0.002
39 | 102kΩ | R2 | R0402 | 1 | 0402WGF1023TCE | UNI-ROYAL(厚声) | LCSC | C26991 | 0.001
40 | 1.96kΩ | R3 | R0402 | 1 | AF0402FR-071K96L | YAGEO(国巨) | LCSC | C705024 | 0.004
41 | 52.3K | R4 | R0402 | 1 | AC0402FR-0752K3L | YAGEO(国巨) | LCSC | C227130 | 0.001
42 | 232K | R6 | R0402 | 1 | AC0402FR-07232KL | YAGEO(国巨) | LCSC | C226360 | 0.001
43 | 10K | R8 | R0402 | 1 | AC0402FR-0710KL | YAGEO(国巨) | LCSC | C144807 | 0.001
44 | 8.66K | R9 | R0402 | 1 | RC0402FR-078K66L | YAGEO(国巨) | LCSC | C185387 | 0.001
45 | 2K | R14 | R0402 | 1 | RC0402FR-072KL | YAGEO(国巨) | LCSC | C60488 | 0.001
46 | 22.1K | R15 | R0402 | 1 | RC0402FR-0722K1L | YAGEO(国巨) | LCSC | C163478 | 0.001
47 | 47.5K | R16 | R0402 | 1 | RC0402FR-0747K5L | YAGEO(国巨) | LCSC | C137974 | 0.001
48 | 10 | R21,R22,R23,R24,R27,R28 | R0402 | 6 | RC0402FR-0710RL | YAGEO(国巨) | LCSC | C138066 | 0.001
49 | 100kΩ | R5,R7 | RES-ADJ-TH_3P-L9.5-W4.9-P2.50-L_3296W | 2 | 3296W-1-104 | BOCHEN(博晨) | LCSC | C118963 | 0.161
50 | 2.2kΩ | R10 | R0603 | 1 | 0603WAF2201T5E | UNI-ROYAL(厚声) | LCSC | C4190 | 0.001
51 | 220Ω | R34 | R0603 | 1 | 0603WAF2200T5E | UNI-ROYAL(厚声) | LCSC | C22962 | 0.001
52 | 1K | R35 | R0603 | 1 | RC0603FR-071KL | YAGEO(国巨) | LCSC | C22548 | 0.001
53 | 4.7K | R36 | R0603 | 1 | RC0603JR-074K7L | YAGEO(国巨) | LCSC | C105428 | 0.001
54 | 0.01Ω | SNT3,SNT2,SNT1 | R2512 | 3 | CUM2512-24FR010 | FORT(致强) | LCSC | C323772 | 0.093
55 | 6.8Ω | R33 | R2512 | 1 | 25121WF680KT4E | UNI-ROYAL(厚声) | LCSC | C48277 | 0.047
56 | SIC461ED-T1-GE3 | SIC461 | MLP55-27_L5.0-W5.0-P0.50-TL_SIC46XXX | 1 | SIC461ED-T1-GE3 | VISHAY(威世) | LCSC | C499531 | 2.231
57 | TS-1092S-B3D2-G | SW1,SW2 | SW-SMD_L6.1-W3.6-LS7.9 | 2 | TS-1092S-B3D2-G | Yuandi(元迪) | LCSC | C520860 | 0.05
58 | LM2596S-5.0RG | LM2596 | TO-263-5_L10.2-W8.9-P1.70-TL-LS15.2 | 1 | LM2596S-5.0RG | HGC(深圳汉芯) | LCSC | C2977092 | 0.422
59 | SN74HCT541PWR | U2 | TSSOP-20_L6.5-W4.4-P0.65-LS6.4-BL | 1 | SN74HCT541PWR | TI(德州仪器) | LCSC | C436096 | 0.341
60 | INA3221AIRGVR | U3 | QFN-16_L4.0-W4.0-P0.65-TL-EP2.2 | 1 | INA3221AIRGVR | TI(德州仪器) | LCSC | C181255 | 0.948
61 | ICM-20602 | U5 | LGA-16_L3.0-W3.0-P0.50-BL | 1 | ICM-20602 | TDK InvenSense(应美盛) | LCSC | C97633 | 2.945
62 | LM75BD | U6 | SOIC-8_L4.9-W3.9-P1.27-LS6.0-BL | 1 | LM75BD | UMW(友台半导体) | LCSC | C725792 | 0.535
63 | DS3231MZ+ | U7 | SOIC-8_L4.9-W3.9-P1.27-LS6.0-BL | 1 | DS3231MZ+TRL | MAXIM(美信) | LCSC | C107410 | 2.258
64 | MICROXNJ | USB | MICRO-USB-SMD_MICROXNJ | 1 | MicroXNJ | SHOU HAN(首韩) | LCSC | C404969 | 0.034
65 | CP2102N-A02-GQFN28R | USB-UART | QFN-28_L5.0-W5.0-P0.50-TL-EP3.3 | 1 | CP2102N-A02-GQFN28R | SILICON LABS(芯科) | LCSC | C964632 | 2.316

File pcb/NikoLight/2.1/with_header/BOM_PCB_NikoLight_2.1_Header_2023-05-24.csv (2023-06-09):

ID | Name | Designator | Footprint | Quantity | Manufacturer Part | Manufacturer | Supplier | Supplier Part | Price
1 | R1210 | R15 | R1210 | 1 | RC1210FR-076R65L | YAGEO | LCSC | C309592 | 0.064
2 | CAP-SMD_L3.5-W2.8-R-RD | C8,C7 | CAP-SMD_L3.5-W2.8-R-RD | 2 | T491B107K010AT | KEMET | LCSC | C122271 | 0.222
3 | HDR-TH_19P-P2.54-V-F | U2,U3 | HDR-TH_19P-P2.54-V-F | 2 | 2.54-1*19P母 | BOOMELE(博穆精密) | LCSC | C319202 | 0.125
4 | HDR-TH_8P-P2.54-V-F-1 | H1 | HDR-TH_8P-P2.54-V-F-1 | 1 | Female headerHDR1X8-2.54 | BOOMELE | LCSC | C27438 | 0.07
5 | R0603 | R12,R13 | R0603 | 2 | RC0603FR-072K2L | YAGEO | LCSC | C114662 | 0.001
6 | R0603 | R14,R9 | R0603 | 2 | RC0603JR-074K7L | YAGEO | LCSC | C105428 | 0.001
7 | R0603 | R11,R1,R2,R3,R4,R5,R6,R7,R8 | R0603 | 9 | RC0603FR-07220RL | YAGEO(国巨) | LCSC | C107696 | 0.001
8 | R0603 | R10 | R0603 | 1 | RC0603FR-071KL | YAGEO(国巨) | LCSC | C22548 | 0.001
9 | SOD-123_L2.7-W1.6-LS3.7-RD | Z1 | SOD-123_L2.7-W1.6-LS3.7-RD | 1 | MMSZ4684T1G | onsemi(安森美) | LCSC | C24672 | 0.046
10 | CAP-SMD_L7.3-W4.3-R-RD | C4,C3 | CAP-SMD_L7.3-W4.3-R-RD | 2 | T491D227K010AT | KEMET | LCSC | C116577 | 0.535
11 | SOT-223-3_L6.5-W3.4-P2.30-LS7.0-BR | T1 | SOT-223-3_L6.5-W3.4-P2.30-LS7.0-BR | 1 | BCP55-16,115 | Nexperia(安世) | LCSC | C56551 | 0.076
12 | FUSE-SMD_L9.8-W5.1 | F1 | FUSE-SMD_L9.8-W5.1 | 1 | 0154005.DR | Littelfuse | LCSC | C206916 | 1.443
13 | F2920 | F2 | F2920 | 1 | ASMD2920-300-30V | JDTfuse(集电通) | LCSC | C2982291 | 0.154
14 | CONN-TH_B2B-XH-A-LF-SN | FAN,SENSOR | CONN-TH_B2B-XH-A-LF-SN | 2 | B2B-XH-A(LF)(SN) | JST | LCSC | C158012 | 0.033
15 | TF-SMD_TF-01A | U4 | TF-SMD_TF-01A | 1 | TF-01A | HRO | LCSC | C91145 | 0.175
16 | CONN-TH_B4B-XH-A-LF-SN | POWER_IN,I2C | CONN-TH_B4B-XH-A-LF-SN | 2 | B4B-XH-A(LF)(SN) | JST Sales America | LCSC | C144395 | 0.047
17 | TO-220-5L_L10.2-W4.5-P1.71-L | LM2596T-5.0,LM2596T-5.0 | TO-220-5L_L10.2-W4.5-P1.71-L | 2 | LM2596T-5.0 | HGSEMI | LCSC | C194354 | 0.749
18 | CONN-TH_3P-P2.50_A2501WV2-3P | LED1,LED3,LED5,LED7,LED2,LED4,LED6,LED8 | CONN-TH_3P-P2.50_A2501WV2-3P | 8 | B3B-XH-A(LF)(SN) | JST Sales America | LCSC | C144394 | 0.041
19 | IND-SMD_L8.5-W8.0_PCC-M0854M | I1,I2 | IND-SMD_L8.5-W8.0_PCC-M0854M | 2 | ETQP5M101YGK | PANASONIC | LCSC | C409630 | 0.703
20 | SMC_L6.9-W5.9-LS7.9-R-RD | D1,D2 | SMC_L6.9-W5.9-LS7.9-R-RD | 2 | SSC54-E3/57T | Vishay Intertech | LCSC | C222482 | 0.403
21 | CAP-SMD_L3.5-W2.8-R-RD | C5 | CAP-SMD_L3.5-W2.8-R-RD | 1 | T520B107M006ATE070 | KEMET(基美) | LCSC | C156457 | 0.362
22 | CAP-SMD_L3.2-W1.6-RD | C6 | CAP-SMD_L3.2-W1.6-RD | 1 | T491A106K006AT | KEMET | LCSC | C122260 | 0.162
23 | CAP-TH_BD10.0-P5.00-D1.0-FD | C2,C1 | CAP-TH_BD10.0-P5.00-D1.0-FD | 2 | 680uF 25V | ValuePro | LCSC | C42281 | 0.05
24 | SO-20_L12.8-W7.5-P1.27-LS10.3-BL | 74HCT541D | SO-20_L12.8-W7.5-P1.27-LS10.3-BL | 1 | 74HCT541D,653 | Nexperia | LCSC | C547781 | 0.536

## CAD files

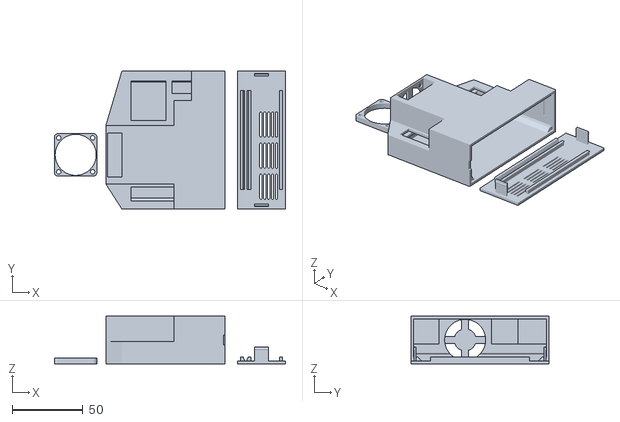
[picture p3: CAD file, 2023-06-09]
model/NikoLight_Case_AIO.stl
163.4 x 97.8 x 33.8

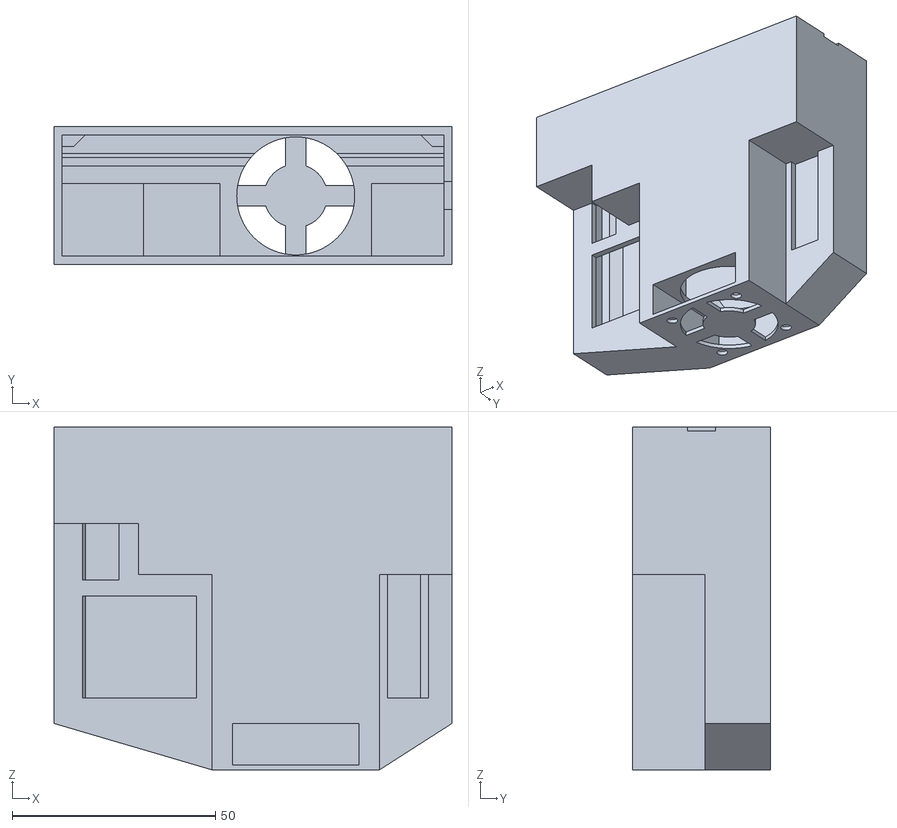
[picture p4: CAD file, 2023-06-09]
model/NikoLight_Case.stl
97.8 x 33.8 x 84.2

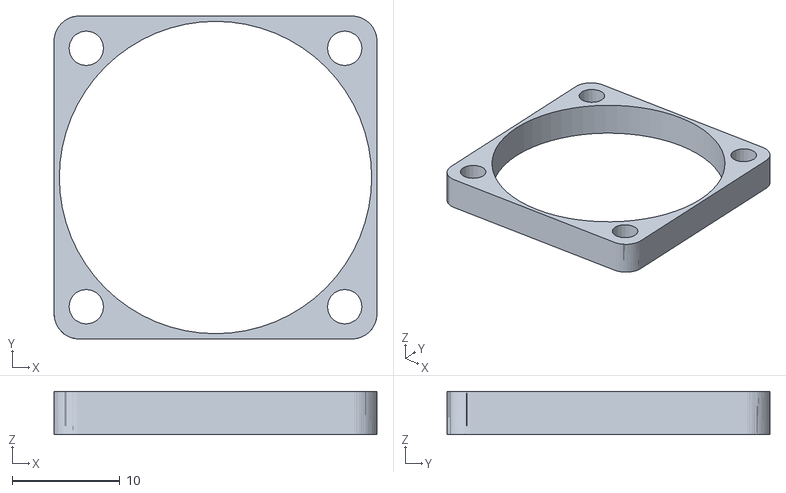
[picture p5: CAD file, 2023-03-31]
model/NikoLight_Fan_Adapter.stl
30.0 x 30.0 x 4.00

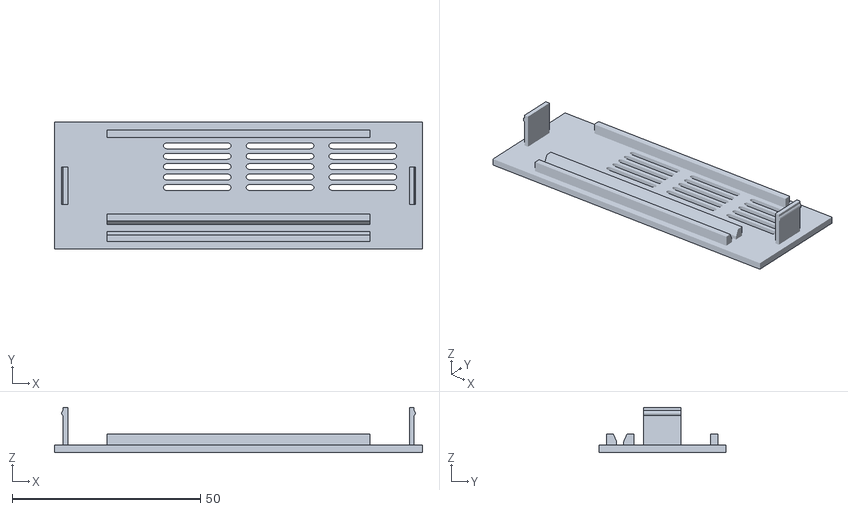
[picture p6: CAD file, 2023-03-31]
model/NikoLight_Case_Cover.stl
97.8 x 33.8 x 12.0

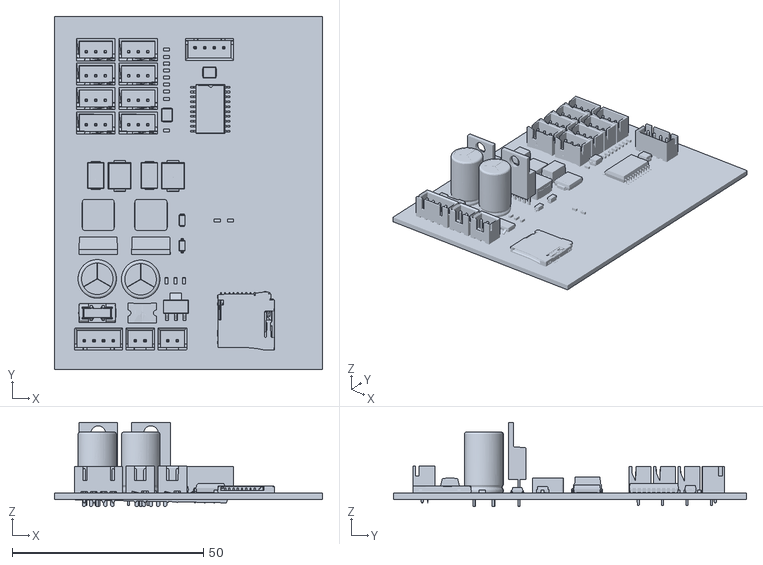
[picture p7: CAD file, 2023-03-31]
model/NikoLight_Board.stl
70.1 x 92.3 x 22.0

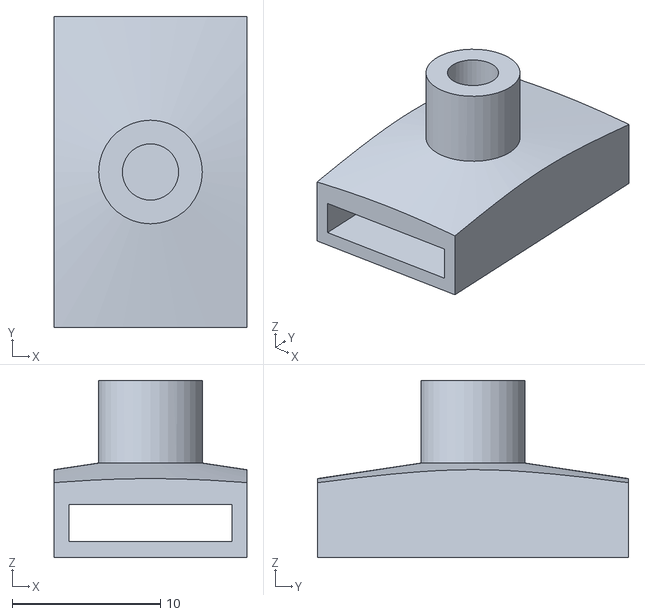
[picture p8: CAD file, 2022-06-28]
model/NikoLight_LED_Case.stl
13.0 x 21.0 x 12.0

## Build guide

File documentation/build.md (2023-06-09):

# Build Guide

Before starting with this guide, make sure to read the [planning](planning.md) document and [part list](part-list.md) first.
They contain important information and some considerations before beginning the project.
If you start to build the project blindly, you might run into issues later.

## General Knowledge about the Hardware

Let's start with some general knowledge about the hardware.
I know this might be boring, but I also have to cover people who want to know more about it.

At first the NikoLight controller is based on an ESP32 microcontroller board, which is placed on a custom PCB.
The ESP32 contains two Tensilica-LX6 cores, running at 80MHz or 240MHz.
They come with 512kB of SRAM and 4MB of flash memory.
Also, they have onboard WiFi (802.11bgn) as well as Bluetooth (classic and LE).
Hardware support for SPI, I2C, CAN, UART, etc. could be used in the future.
Generally the board operates at the 3.3V level.
It has a voltage regulator which will provide the 3.3V from the 5V, provided by the NikoLight PCB.
If you plan to do your own customisations please keep in mind that all IO pins can only handle 3.3V and a very limited current in the range of a few milliamps.

The NikoLight PCB contains a few active and passive components.
First of all, there is voltage regulator, providing stable 5V to the LEDs and the ESP32 board.
To be more precise, there now are two channels that can provide a max of 3A per channel or 6A in total.
There is no force to build both channels.
The board also works with a single regulator but then the output power is more limited of course.
For a single regulator build the Jumper 'J1' should be closed.

By default the channels of the regulators are not connected but of course they share a common ground.
The reason for not connecting them is that this can lead to trouble due to manufacuting tolerances.
If one of the two regulators provides a slightly higher voltage than the other regulator, most of the load will be driven by the regulator with the higher voltage.
This could lead to one regulator overheating and also to unwanted osccilations.
In case you feel confident connecting the outputs together, this is possible via the jumper `J1`.
Otherwise each regulator will drive 4 output channels.
The first regulator will drive the channels 2, 4, 6, 8 and the second regulator will drive the channels 1, 3, 5, 7.

The dual regulator build is always recommended to be more flexible and have more headroom.
When properly configured, the software will now also keep an eye on your power consumption.
The power draw is calculated and limited for each regulator by limiting the LED brightness.
Also two temperature sensors can be added to the regulators. For Temperature Sensor Install Position see following picture:

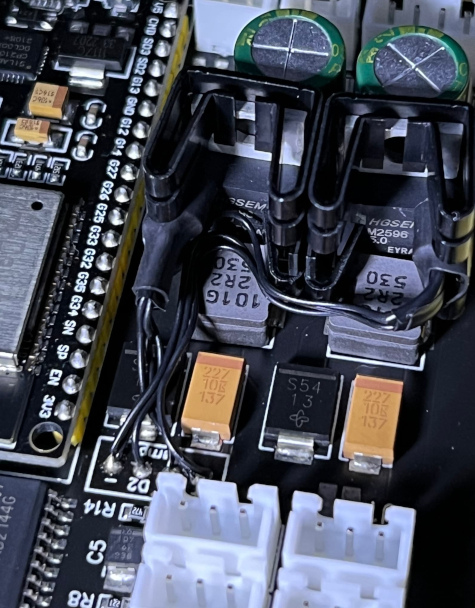
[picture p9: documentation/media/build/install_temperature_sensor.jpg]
Temperature Sensor Install Position


The software will then also check for the temperature, control a cooling fan and reduce the power output if necessary.
For even more protection there is a fuse and a poly fuse in place.

The regulators can handle an input voltage of up to 45V according to the [specs](https://www.ti.com/lit/ds/symlink/lm2596.pdf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), which makes the board also very usable for 24V applications.
But keep in mind that the input capacitors might need to be changed and that these 45V are an absolute maximum rating.

Next the PCB holds a MPU6050 motion sensor.
It is used for interactive animations using acceleration and rotation data.
The sensor is suitable for up to 16g's but NikoLight is using a limit of 2g's currently.
If anyone can prove to me that 2g's are not enough in a Tesla, then I will congratulate you and we can talk about setting it to 4g in the software😋.
Hidden challenge?
I... I would never challenge you to do stupid things...

Girl Shy

Umm... we better continue... So... where did we stop?

Since we learned the hard way that it is not a good idea to drive WS2812-type LEDs with a 3.3V signal, there now is a 74HCT541D on the board.
It can safely read the 3.3V data signals from the ESP32 board and convert it to a 5V level.
This now allows us so safely drive all kind of WS2812-type LEDs, even over longer signal wires.

There is also a voltage divider, with a following low-pass filter used to lower and smooth the voltage of the sensor pin
It can then be used by the ESP32 and converted into a digital value using it's ADC (analog digital converter).
This pin can be connected to your car's existing ambient light to give NikoLight a signal when to turn on and off or to adjust the brightness automatically.

Lastly, there are some passive components like resistors and capacitors to protect the data lines, pull the I2C data lines to 3.3V and to smooth some things out...
I guess we are getting too basic here...

Like mentioned the used LED type is WS2812 or compatible.
These LEDs have integrated controllers, capable of receiving a digital 24 bit colour value.
When connected in series they function as a shift register.
NikoLight is able to drive a variable number of LEDs in series (up to a few hundred).
The LEDs operate at 5V and **only 5V**.
Never connect them directly to the 12V of your car.
If you are using other LEDs that are 12V compatible and share the same data protocoll, make sure to never feed 12V into the NikoLight board via the power output or data pins.

The following picture shows the pinout of the NikoLight board.

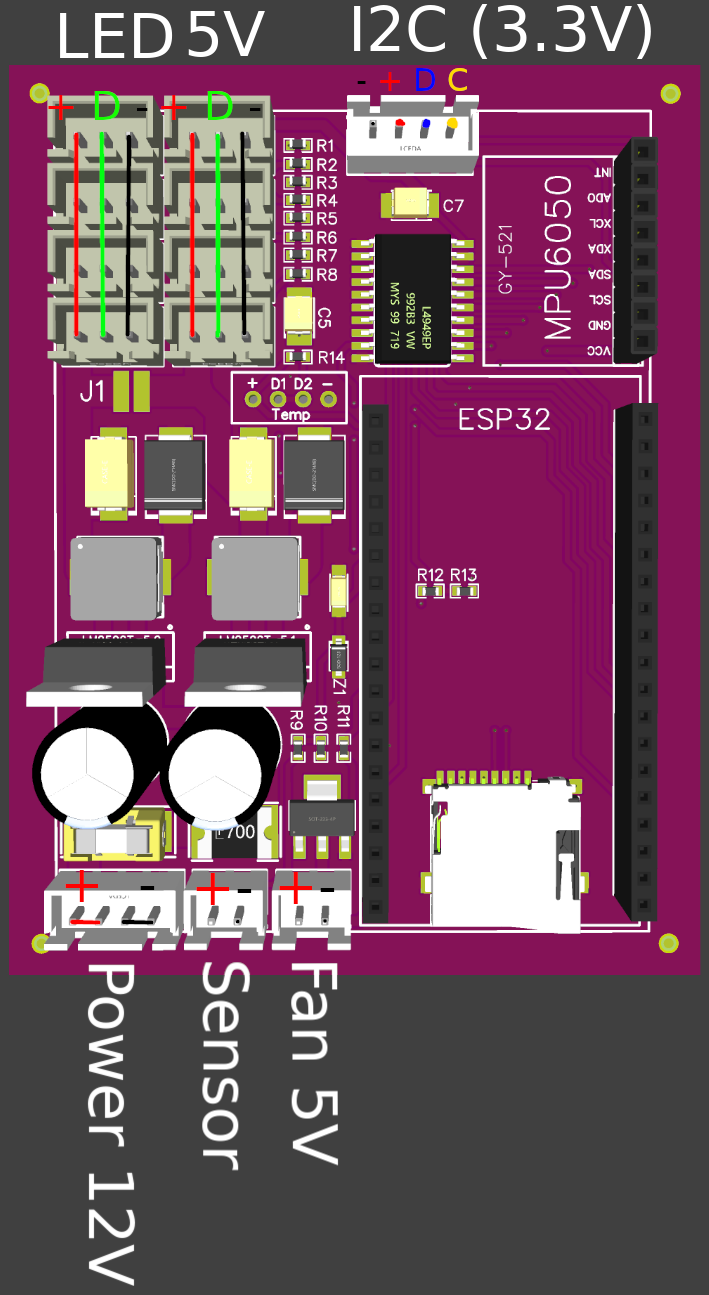
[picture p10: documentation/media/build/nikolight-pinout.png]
NikoLight Pinout


As you can see there are 8 connectors for the LED outputs.
These provide power to your LEDs and a data signal suitable for driving the WS2812 type.
The connectors are ordered like this:

| 1 | 2 |<br>
| 3 | 4 |<br>
| 5 | 6 |<br>
| 7 | 8 |

By default these outputs are mapped to the following zones.
This mapping can be changed via the (build time) configuration.
However the mapping was not chosen randomly and should only be changed if you know what you are doing.
Since there now are 2 voltage regulators, the power draw should be split as even as possible between the regulators.
The mapping was chosen based on this criteria.

| Channel | Mapped to |
| --- | --- |
| Channel 1 | Dash |
| Channel 2 | Center console |
| Channel 3 | Front left door  |
| Channel 4 | Front right door |
| Channel 5 | Rear left door |
| Channel 6 | Rear right door  |
| Channel 7 | Footwell left |
| Channel 8 | Footwell right |

At the bottom of the PCB there are 3 connectors, a micro USB port and a micro SD card slot.

The 4 pin XH connector is for powering the board.
The input voltage can be up to 45V with suitable capacitors (absolute maximum rating).
Keep in mind that according to the picture diagram above, the right pin is connected to ground.
Never connect the ground pin to the positive wire of your footwell lights.
If you are sure that there is a good ground connection, which is usually the case, there is no need to use it.
One last thing to keep in mind is that only positive voltages can be measured, so avoid doing something crazy with this simple input.

The center 2 pin XH connector can be used as a sensor to measure the voltage of your car's ambient light and supply NikoLight an on/off or brightness signal.
The pin can be used with analog voltages and also PWM signals due to the low-pass filter.
It is recommended to not measure voltages above 19V with this controller.
There is an overvoltage protection in place and exceeding this limit for a short period should be possible but not recommended.
Instead the resistor `R9` and `R10` of the voltage devider can be adjusted accordingly.
Use an "electricity thief" to get the signal of the factory build footwell lights without harm. It could look like this if you add the correct plugs to get the signal without any harm. See [part list](part-list.md).

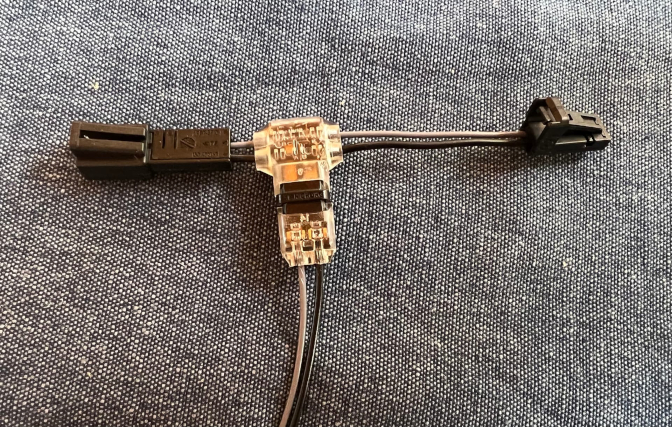
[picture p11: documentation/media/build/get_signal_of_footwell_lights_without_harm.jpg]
get signal of footwell lights without harm

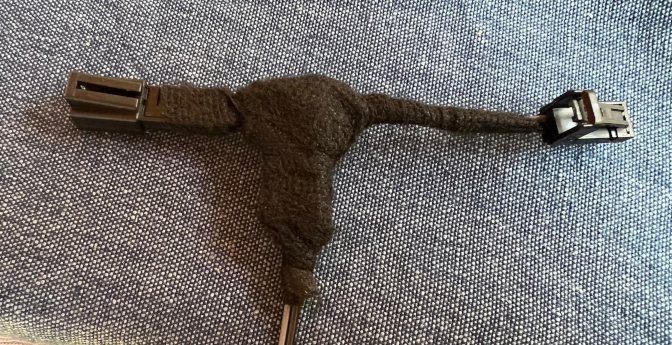
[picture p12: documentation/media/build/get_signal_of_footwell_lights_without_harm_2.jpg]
get signal of footwell lights without harm 2


Another 2 pin XH connector is for powering an optinal, 5V cooling fan.

There is a micro USB port on the ESP32 board which will later be used to upload the software.
This should be a one time proceedure due to the OTA (wireless) updates.
The micro SDCard is required by NikoLight.
It's used to save configuration data, UI files and custom animations of the user.

## Clone or Download the Project Files

Alright, now the point has come where we can start.
At first you should clone or download the project files.
Go to the [project's main page](https://github.com/TheRealKasumi/NikoLight) and click the `Code` button.
You can then decide if you want to clone the repository using [Git](https://git-scm.com/) or [download](https://github.com/TheRealKasumi/NikoLight/archive/refs/heads/main.zip) it as zip file.

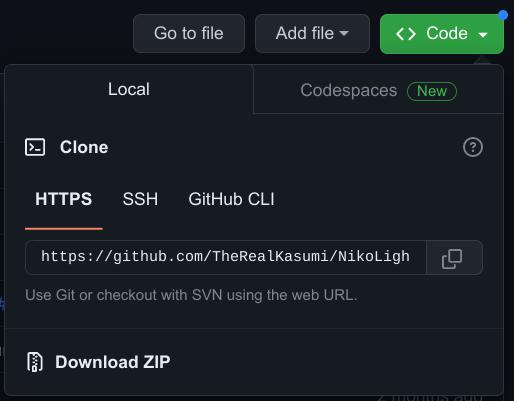
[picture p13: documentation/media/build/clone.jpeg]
Clone


As an alternative you can also go to the releases and download one of them.

### Using Git

- Open a terminal in your destination folder
- Run `git clone https://github.com/TheRealKasumi/NikoLight.git`
- A folder `NikoLight` will be created, containing all project files

### Download as Zip

- Click the [download link](https://github.com/TheRealKasumi/NikoLight/archive/refs/heads/main.zip)
- Extract the NikoLight folder

## Order the PCB and 3D Printed Parts

Like already mentioned in the [part list](part-list.md), the PCB and 3D printed parts can be ordered at [JLCPCB](https://jlcpcb.com/).
But of course you are free to order the parts somewhere else or create them by yourself.

Open their website and click on [Order Now](https://cart.jlcpcb.com/quote) on the right, top of the page.
This should bring you to the configuration page where you can upload the files and configure the PCB.

### Upload Gerber Files

First, the so-called `gerber files` should be uploaded.
These contain all the data required to produce the PCB.
They can be found in the [/pcb/gerber](/pcb/gerber/) folder of the project.

Now two different versions are available.
One version of the board comes with pre-installed DIP headers so that no soldering is required for the board.
The other version has no such header to save space.
Therefore soldering the ESP32 and MPU6050 to the board is required.
Choice is yours

JLCPCB requires you to upload one the zip archives with the gerber files first.
Click on `Add gerber file` on the configuration page and then upload the zip archive of your choice.
Once upload and processing is done, you will see a preview of the PCB.
It should look like this, with the two left images:

PCB

### Board Configuration

Generally, you should be fine with their default configuration but you are free to modify it if you wish.
However, keep in mind that this can have a big effect on the price.
Changing the number of layers and dimensions is not recommended and can lead to problems later.
Also the PCB shouldn't be too thin.
Here the default 1.6mm is just perfect.
For a nice look I would recommend black or purple PCBs, even if the build time is a little higher usually.

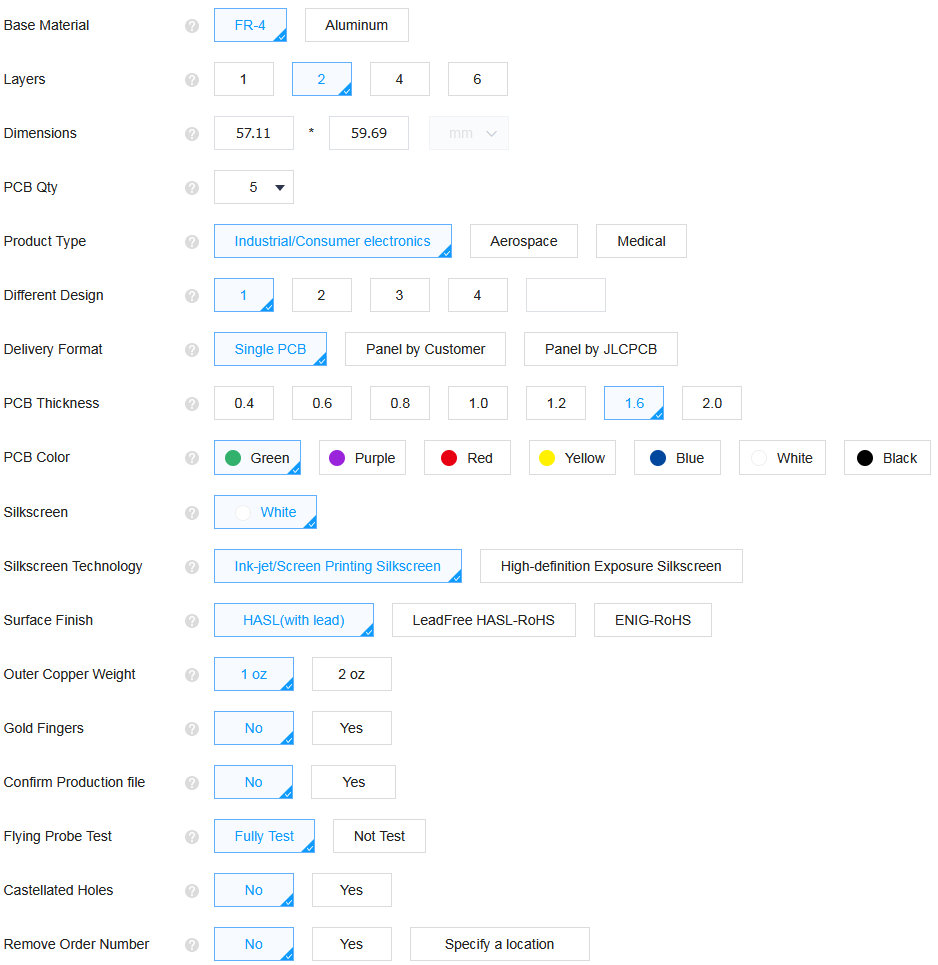
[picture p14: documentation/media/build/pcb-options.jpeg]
PCB Options


### Assembly Service

When you are done, configuring the PCB, then it's time to configure the assembly service.
At first you need to chose one of their assembly services.
`Economic` and `Standard` are the available options.

Economic:

- Cheaper
- Collection of boards of different customers are created together
- No borders required
- Takes longer

Standard:

- More expensive
- Your boards are checked, adjusted and produced individually
- Borders and markers are required
- Faster production

Once more, choice is yours but `Economic` is recommended.
Assembly side must always be `top`.
Tooling holes should be added by JLCPCB and confirmation of parts placement is recommended.

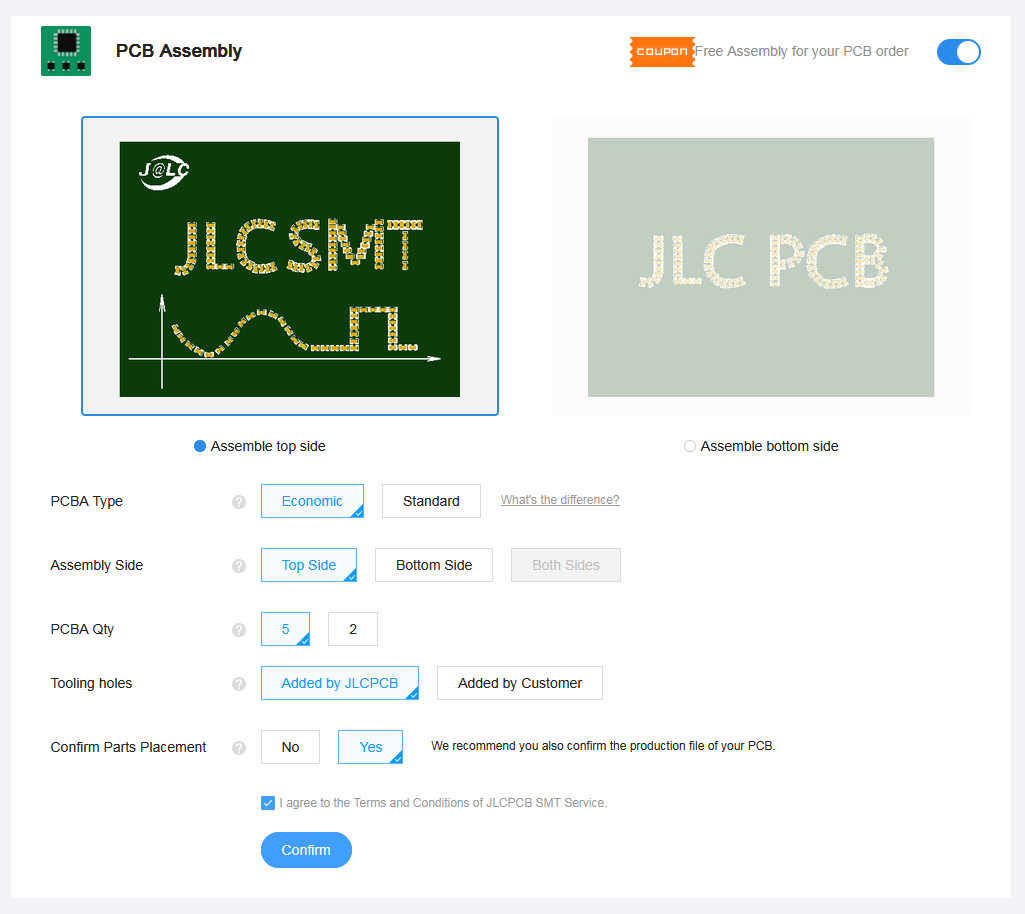
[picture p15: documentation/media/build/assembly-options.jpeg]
PCB Options


Once you are done, click on `Confirm`.

### Upload BOM and Placement Files

On the next page you need to upload the BOM (material list) file.
This file contains all components that should be placed on the board.
At the same time you need to upload a so called "pick and place" file.
It is used for the correct component placement.
Make sure to upload the correct files, matching your board version.
Click next to move to the following step.

### Select the parts that should be placed

On this page you should check if all parts are available.
Also you can select whcih components should be installed.
If you want to install a few components on you own, you can unselect them here.
Once done click next and add the items to your shopping cart.

### Upload or Print 3D Files

Ordering works very similar to the steps described above.
Go back to the [order page](https://cart.jlcpcb.com/quote) and select `3D-Printing` at the top of the page.
The 3D files can be found in the [/model](/model/) folder of the project.

In a normal build you will need both, the [NikoLight_Case.stl](/model/NikoLight_Case.stl) and the [NikoLight_Case_Cover.stl](/model/NikoLight_Case_Cover.stl).
The all-in-one verion [NikoLight_Case_AIO.stl](/model/NikoLight_Case_AIO.stl) can be used as an alternative.
When you are using a smaller 30x30x6mm fan, the [NikoLight_Fan_Adapter.stl](/model/NikoLight_Fan_Adapter.stl) is recommended.
If you plan to use fiber cables and LED injectors, the [NikoLight_LED_Case.stl](NikoLight_LED_Case.stl) should be ordered as well.
The number depends on the number of light injectors you want to use for the fibre tubes.

Generally the material choice shouldn't be a metal.
The cases must **NOT** be electrically conductive but it is otherwise up to you.
A recommendation is to use a more heat resistant material like ABS or PETG.
Ideally a flame-retardant material is used.

When you plan to print the case yourself, the following setup is recommended:

- Nozzle: 0.4 - 0.6mm
- Layerheight 0.1 - 0.2mm

### Order

Open your shopping cart and make sure it contains all required items.
Then complete the order.

## Assemble the NikoLight Controller

### Fully Assembled Boards

Your boards will be produced and assembled by the PCB serivce.
Insert the MPU6050 and ESP32 boards into their place and you are done.
The ESP32 USB port should point to the bottom.
Pay attention to not install it the wrong way around.
The MPU6050 is installed so that the PCB points to the left when the ESP32 USB port is pointing towards you.
That's it, you went for the simple way and you are done😋.

### Manual Assembly

First, make sure you have all required parts.
Go back to the [part list](part-list.md) if you want to check it again.
Prepare your tools, pre-heat the soldering station and then the "fun part" can start😋.

#### Soldering of small Components

I would recommend to start with the small components first.
For the small components I created a short video to show how it can be done.
Especially when you are new to SMD components, it is recommended to watch the video first and follow the steps shown.
Some steps might be missing or are different depending on your board version.
But since you are a tinkerer, I am sure you can do it.

NikoLight Demo (https://www.youtube.com/watch?v=Nh1XLG8EGs4)

#### Soldering the remaining Components

Generally the remaining components are soldered with the "through-hole technique".
For this cut the legs of the components so that they are just long enough to reach the other side of the PCB.
Insert the component and flip the PCB around.
Always pay attention to the polarity of the components.
Capacitors can potentially explode and hurt your ears and eyes when you insert the in the wrong way around.
Please be careful about that.

Heat up the contects and feed some solder to it until the component is soldered to the board nicely.
It's the same process for all remaining components.
Which exact component to use is printed on the backside of the PCB.

Before you install the ESP32 and MPU6050, you can relatively safely test the voltage regulators.

##### Test the Voltage Regulator

This step is optional but highly recommended.
When you finished building the regulator, please take some time to test it.
If there is a malfunction, it could damage all your other parts.
So it's definitely worth the time.

To test the regulator power the PCB with a voltage above 7V.
It would be good practice to use a low current limit like 250mA.
The polarity and right connections were already shown at the beginning of the guide.
You should then be able to measure a voltage of 5V at the LED outputs.

NikoLight Pinout

Increase the Voltage up to 18V if possible.
The output voltage should stay stable at 5V and the input current should stay very low (usually less than 10mA).
If you have the option to add a load to the 5V side, please test it out.
1A of load is a good test.
If the voltage doesn't break down under load, the build of the regulators was successful.
Once you are done, you can solder all remaining parts to the PCB.

#### ESP32

There is nothing special about installing the ESP32 on the board.
Make sure to push all pins through the holes, move it as far down as possible and cut the legs on the backside.
Solder them to the PCB and you are done.

> Maybe you want to wait with this step and test if everything works first.
> Just push all pins in the holes and let the ESP start up when you uploaded the software.
> Desoldering the ESP32 board is no fun.
> So it might be worth a test first.
> You may find you have bad contacts.
> So it's recommended to push the board a little bit against the PCB to ensure good contact.

When you are done, the NikoLight controller should look similar to this (some components might look a little different):
Controller

## Install position in car

It would be best if the antenna of the ESP32 points to the front and the USB port to the back of the vehicle. This way we ensure consistent acceleration directions from the sensor for all users.

## Assemble the LED Injectors (optional for fiber cables)

First of all you should make sure to have the correct number of cases and LEDs.
Also it's recommended that you have an good idea of where you want to place the LEDs, how many and what the wire lengths are.
It will save a lot of trouble to do good planning prior.

Building the "light injectors" is pretty straightforward.
All you need to do is to connect the LEDs with the wires, pay attention to the wire lengths and then push them into their case.
The LEDs are connected like shown in the following picture.
Pay attention to the polarity and everything will work out fine.

LED Connection

If you are done building the chains and inserting the LEDs into their case, it's recommended to apply some glue so they can't slip out again.
Fabric tape can also be used to fix them in place.
Also, you can use it to wrap the wires and avoid unwanted noises when driving.
Last step is to solder or crimp the XH 3 pin male connector to the first LED.
The following picture shows the pinout.

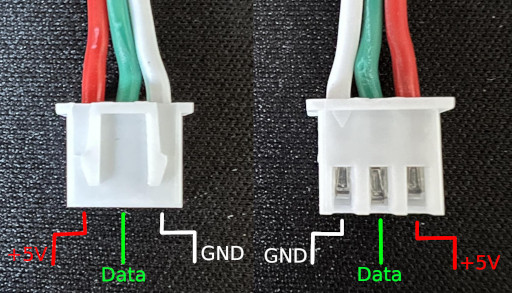
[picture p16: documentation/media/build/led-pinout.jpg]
LED XH Pinout


When one "injector chain" is done, it should look something like this.

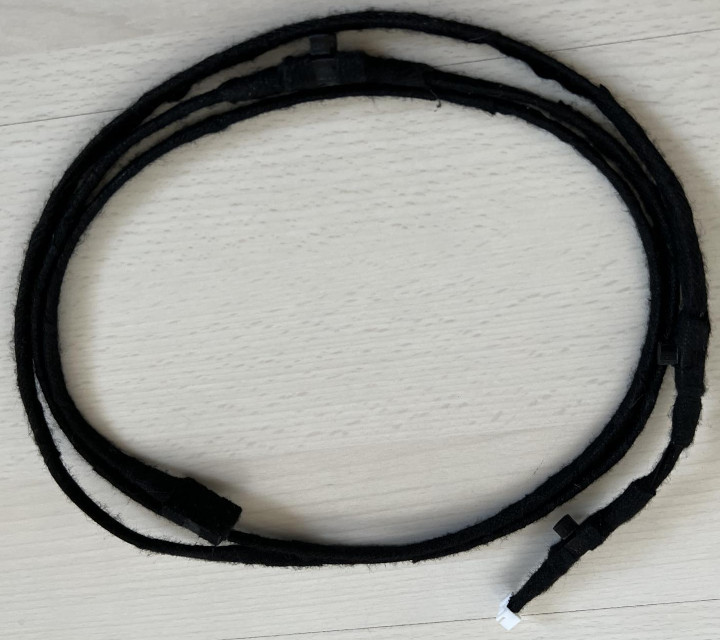
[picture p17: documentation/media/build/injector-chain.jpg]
LED Injector Chain


As you can see it's also possible to solder a female connector to the first LED and then use an extension cable.
This allows to easily replace the LEDs in case one dies at some point in the future.
But this is entirely optional.

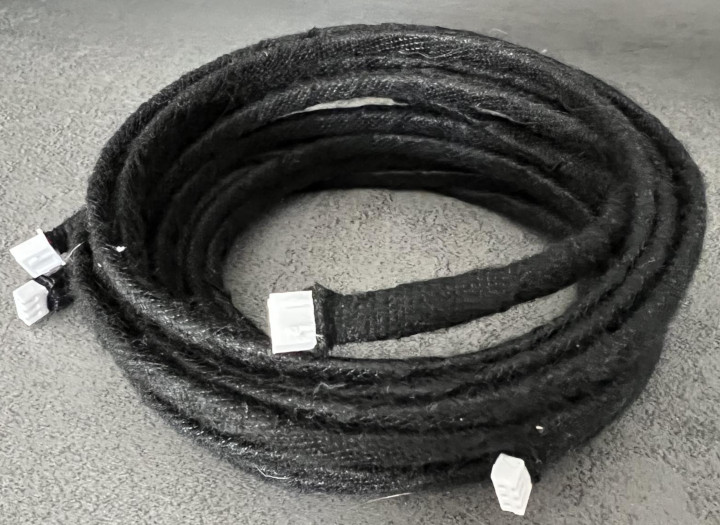
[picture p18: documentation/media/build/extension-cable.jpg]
Extension Cable


## Attach Wires to LED Strips (optional for LED Strips)

This is very much the same procedure as for the LED injectors.
Usually to connections for WS2812 LED strips is as follows.

LED Connection

Make sure to correctly install the cables and connectors.
Once again, this is how the connections should look at the end.

LED XH Pinout

## Attach Wires to Light Bars (optional for Light Bars)

Since the light bars also only use an LED strip internally, the procedure is the same as for the LED strips above.
However, depending on the light bars, the polarity might be different.
It is highly recommended, to open the light bar at the cable end to check on the polarity.
We already encountered the same type of light bars with different cable colors for the connections.
So please be careful and don't trust the cable colours.
How to check: The middle cable (green?) should always be data. Then plug one cable to GND and connect the other one with a 220 Ohm resistor to 5 V. If the strip turns on, then everything is good. If not, try the other way around. There should be no current flowing through the resistor high enough to damage the strip.

At the end the 3 pin XH connectors must have the following pinout.

LED XH Pinout

## Upload the Software

### NikoLight Controller

Uploading the software is the final step before you can test your work.
Please install the following software and extension for the upload procedure:

- [Git](https://git-scm.com/downloads)
- [VS Code](https://code.visualstudio.com/download)
- [PlatformIO](https://platformio.org/install/ide?install=vscode)
- [NodeJS](https://nodejs.org)
- [NPM (comes with NodeJS)](https://www.npmjs.com/)

Start VS Code and then open the [mcu](/mcu/) folder of the project.
You can do so by clicking `File` -> `Open Folder...`.
On the left all files inside the opened folder should be listed.
Open the file `platformio.ini`.
In the configuration you can see two attributes, `upload_port` and `monitor_port`.

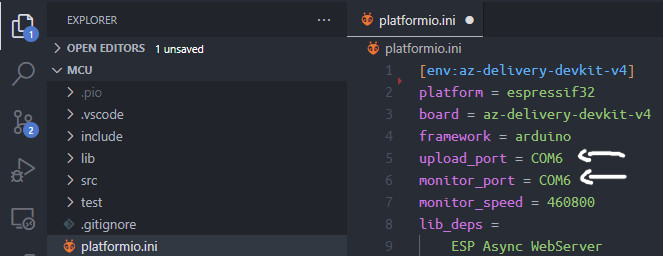
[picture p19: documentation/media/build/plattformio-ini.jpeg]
plattformio.ini


Connect the NikoLight controller to your computer via a micro USB cable.
Now you need to find out which port the controller was assigned to.
The recommendation is to use the device manager when you are using Windows.
Press the Windows key + R and type `devmgmt.msc`.
Then hit enter.
The device manager will start up and you should be able to identify the port of the controller.
Go back to the `platformio.ini` and adjust the port.
For Linux and Unix users I will not even explain this step.
They should know how this works, right😛?
Once changed, you can save the file and close it.

Now there is one more configuration step before you are ready to upload the code to the board.
Please navigate to [include/configuration](/mcu/include/configuration) and open the file [SystemConfiguration.h](/mcu/include/configuration/SystemConfiguration.h).

If you decided to only install one voltage regulator, please do the following changes:

- `#define REGULATOR_COUNT 1`
- `#define REGULATOR_ZONE_MAPPING {{13, 0}, {14, 0}, {15, 0}, {16, 0}, {17,0}, {21, 0}, {22, 0}, {25, 0}}`

Also depending on the board version, the following changes are required.

Board version 1.0 (@luap):

- `#define REGULATOR_COUNT 1`
- `#define REGULATOR_ZONE_MAPPING {{13, 0}, {14, 0}, {15, 0}, {16, 0}, {17,0}, {21, 0}, {22, 0}, {25, 0}}`

Board version 2.0 (@PhilippDen):

- `#define LED_DEFAULT_OUTPUT_PINS {13, 17, 14, 21, 15, 22, 16, 25}`
- `#define REGULATOR_ZONE_MAPPING {{13, 0}, {17, 1}, {14, 0}, {21, 1}, {15, 0}, {22, 1}, {16, 0}, {25, 1}}`

Save the files and then click the upload button in the bottom left.

Upload Button

The code should now be compiled and uploaded to the board.
In case the upload fails, hold down the `boot` button on the ESP32 until the upload started.

Now open the serial monitor by clicking the "plug" button, near to the upload button.

Serial Button

You should see the NikoLight controller starting up, but then stops with `Failed to initialize SD card`.

```shell
NikoLight Firmware version 1.0.0

00:00:00:059 [INFO] (src/main.cpp) (setup) (331): Initialize SD card.
[   364][E][sd_diskio.cpp:199] sdCommand(): Card Failed! cmd: 0x00
[   364][E][sd_diskio.cpp:802] sdcard_mount(): f_mount failed: (3) The physical drive cannot work
[   666][E][sd_diskio.cpp:199] sdCommand(): Card Failed! cmd: 0x00
00:00:00:666 [ERROR] (src/main.cpp) (setup) (338): Failed to initialize SD card.
```

### Prepare and insert the Micro SD Card

NikoLight **requires** a `FAT` or `FAT32` formatted micro SD card.
At least 128MB of storage is recommended for upcoming features.
Well... we live in year 2022.
So just throw a 4GB+ card inside and be done.
The SD card is used to store your settings, animations, logs and the browser based UI.
Also, it can be used to save and play `fseq` files, with fully customized animations.

Since the controller will create the settings and log data automatically, only the UI files must be copied to the SD card.
These can be found in the [ui](/ui/) folder.
But not so fast, there is a mandatory build step first.
Open a terminal of your choice and navigate to the mentioned folder.
Once you are there, please run the following commands.

```sh
npm install
npm run build
```

This can take a moment and should create a [dist](/ui/dist/) folder.
Create a new folder called `ui` in the root of your SD card.
Copy the content of [dist](/ui/dist/) into the newly created folder.
Eject the SD card from your computer and insert it into the micro SD card slot of the NikoLight controller.

## Let's test it

Now that everything is ready, it's time for a short test.
Connect the board back to your computer and fire up the serial monitor.
If required, press the reset button on the ESP32 board.
If everything works, you should see the following (or similar) output:

```shell
Nikolight Firmware version 1.0.0

00:00:00:059 [INFO] (src/main.cpp) (setup) (331): Initialize SD card.
00:00:00:071 [INFO] (src/main.cpp) (setup) (334): SD card initialized.
00:00:00:072 [INFO] (src/main.cpp) (setup) (342): Switching to SD card logger.
00:00:00:593 [INFO] (src/main.cpp) (setup) (346): Switched to SD card logger.
00:00:00:645 [INFO] (src/main.cpp) (setup) (354): Check if system update is available.
[   674][E][vfs_api.cpp:104] open(): /sd/update/update.nup does not exist, no permits for creation
00:00:00:675 [INFO] (src/main.cpp) (setup) (362): No available system update found.
00:00:00:832 [INFO] (src/main.cpp) (setup) (365): Initialize, load and save configuration.
[  1045][E][vfs_api.cpp:104] open(): /sd/config.tli does not exist, no permits for creation
00:00:01:046 [ERROR] (src/util/BinaryFile.cpp) (open) (46): Failed to open binary file.
00:00:01:262 [ERROR] (src/configuration/Configuration.cpp) (load) (158): Failed to load configuration file: /config.tli
00:00:01:289 [ERROR] (src/main.cpp) (initializeConfiguration) (140): Failed to initialize runtime configuration from MicroSD card.
00:00:01:556 [WARN] (src/main.cpp) (setup) (372): Failed to load configuration. Loading defaults and continue.
00:00:01:825 [INFO] (src/main.cpp) (setup) (376): Updating log level from configuration.
00:00:02:049 [INFO] (src/main.cpp) (setup) (379): Log level updated from configuration.
00:00:02:071 [INFO] (src/main.cpp) (setup) (381): Initialize LED Manager.
00:00:02:093 [INFO] (src/main.cpp) (setup) (383): LED Manager initialized.
00:00:02:121 [INFO] (src/main.cpp) (setup) (385): Initialize light sensor.
00:00:02:145 [INFO] (src/main.cpp) (setup) (387): Light sensor initialized.
00:00:02:167 [INFO] (src/main.cpp) (setup) (389): Initialize motion sensor.
00:00:02:205 [INFO] (src/main.cpp) (setup) (392): Motion sensor initialized.
00:00:02:228 [INFO] (src/main.cpp) (setup) (399): Initialize WiFiManager.
00:00:02:250 [INFO] (src/wifi/WiFiManager.cpp) (WiFiManager) (16): Initializing WiFi manager.
00:00:02:402 [INFO] (src/wifi/WiFiManager.cpp) (WiFiManager) (18): WiFi manager initialized.
00:00:02:427 [INFO] (src/main.cpp) (setup) (401): WiFi manager initialized.
00:00:02:449 [INFO] (src/main.cpp) (setup) (403): Starting Webserver.
00:00:02:471 [INFO] (src/server/WebServerManager.cpp) (WebServerManager) (20): Starting webserver on port 80.
00:00:02:495 [INFO] (src/server/WebServerManager.cpp) (WebServerManager) (25): Webserver running.
00:00:02:521 [INFO] (src/main.cpp) (setup) (405): Webserver started on port 80.
00:00:02:549 [INFO] (src/main.cpp) (setup) (407): Initializing REST api.
00:00:02:588 [INFO] (src/main.cpp) (setup) (409): REST api initialized.
00:00:02:610 [INFO] (src/main.cpp) (setup) (411): Load LEDs and animators from configuration using the LED Manager.
00:00:02:661 [INFO] (src/main.cpp) (setup) (414): LEDs and animators loaded.
00:00:02:683 [INFO] (src/main.cpp) (setup) (421): Creating to WiFi network.
00:00:02:707 [INFO] (src/wifi/WiFiManager.cpp) (startAccessPoint) (40): Starting WiFi access point with ssid 'NikoLight' and password 'NikoLightPW' on channel 1.
00:00:02:737 [INFO] (src/wifi/WiFiManager.cpp) (startAccessPoint) (53): Starting WiFi access point.
00:00:02:859 [INFO] (src/wifi/WiFiManager.cpp) (startAccessPoint) (56): Configuring WiFi access point.
00:00:02:882 [INFO] (src/wifi/WiFiManager.cpp) (startAccessPoint) (61): WiFi access point started. Listening on: 192.168.4.1
00:00:02:905 [INFO] (src/main.cpp) (setup) (424): WiFi Network created.
00:00:02:934 [INFO] (src/main.cpp) (setup) (431): Initialize timers.
00:00:02:955 [INFO] (src/main.cpp) (initializeTimers) (243): Initialize timers.
00:00:02:977 [INFO] (src/main.cpp) (setup) (433): Timers initialized.
00:00:02:999 [INFO] (src/main.cpp) (setup) (435): NikoLight initialized successfully, going into work mode.
00:00:12:983 [INFO] (src/main.cpp) (loop) (488): LEDs running at an average of 60 FPS
```

When this is the case, you successfully built the NikoLight controller.
Success!
Now search for a WiFi network called `NikoLight`.
Connect to it using the default password `NikoLightPW` and open up `192.168.4.1` in your browser.
Now the NikoLight UI should show up.
Bookmark this page so that you will not forget it.
Alternatively, you can also try to "install" the UI on your device.
Since it is a ReactJS based UI, some devices offer support for this.

From here you can control NikoLight using the browser based UI.
But don't forget to connect to the `NikoLight` WiFi first.
The ssid and password can be changed in the settings.
I am sure you will figure out how the UI works :) .

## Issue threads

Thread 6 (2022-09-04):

Some links in documentation are broken

TheRealKasumi, 2022-09-04:
Currently some links in the documentation seem to be broken. They need to be fixed.

- [x] find broken links
- [x] fix them

Closed 2022-09-04.

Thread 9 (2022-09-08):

Documentation: Build guide

TheRealKasumi, 2022-09-08:
After the planning (#2) and parts (#3) were documented, it's time to write the build guide.

- [x] How to order the PCB and printed parts
- [x] Build the TesLight controller
- [ ] Build the LED injectors
- [x] Upload the software
- [x] Prepare the SD card
- [ ] Test run
- [x] Link it to the readme

Closed 2022-09-17.

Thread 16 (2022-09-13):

Check if the controller case fits the onboard voltage regulator

TheRealKasumi, 2022-09-13:
Looking at it today I had some doubts the controller fits in the current case with the onboard voltage regulator.

- [x] Check if it fits
- [x] Fix it otherwise

Closed 2022-09-17.

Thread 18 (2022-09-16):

Exclude generated frontend html file from GitHub's coding language detection

TheRealKasumi, 2022-09-16:
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

This needs to be fixed because it's dumb.

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

TheRealKasumi, 2022-10-02:
This issue resolved itself since the huge, packed html file with embedded images ect is gone now. Since the latest update the server is now able to handle multiple files and so this file was removed.

Closed 2022-10-02.

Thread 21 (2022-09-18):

Access log via rest API and UI

TheRealKasumi, 2022-09-18:
The log file created by the controller should accessible via the rest API and UI. This should allow to access it easily without removing the MicroSD card. Also, it makes it easier to report and trace bugs.

- [ ] Get the log via rest API
- [ ] Clear the log via rest API
- [ ] Make it accessible via the UI

Closed 2022-10-03.

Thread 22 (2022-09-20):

Bug in timer for light sensor

TheRealKasumi, 2022-09-20:
In the main loop there is bug in the timer related to the light sensor. There `millis()` instead of `micros()` is used. This isn't breaking anything but should be fixed.

TheRealKasumi, 2022-09-30:
Closed when updating to latest ESP32 core.

Closed 2022-09-30.

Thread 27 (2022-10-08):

Missing documentation for C2 and C3

TheRealKasumi, 2022-10-08:
It was mentioned that there is no documentation for the capacitors `C2` and `C3` which is correct.

- [ ] Add documentation and build steps for these two components

TheRealKasumi, 2022-11-02:
Closing this because it will be outdated with the new hardware v2. See #36 .

Closed 2022-11-02.

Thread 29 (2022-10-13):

Add a power limit option

TheRealKasumi, 2022-10-13:
It would be good if there is an option to configure a power limit for the LEDs to protect the voltage regulator.

- [x] Implement power limiting feature for the controller
- [x] Make it configurable via the settings
- [x] Expose settings to the Ui

Closed 2022-10-14.

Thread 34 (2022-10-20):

New frontend is missing the option to change the LED count

TheRealKasumi, 2022-10-20:
When updating to the new UI the option to change the number of LED per channel went missing.

- [x] Bring the option back

Closed 2022-10-20.

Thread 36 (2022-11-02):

Move to new hardware version 2

TheRealKasumi, 2022-11-02:
Recently a new hardware prototype was designed. It should solve flickering issues with some types of LEDs due to a too low signal voltage. Also it now gives the option to use a second voltage regulator and so split the load. Allowing for a total power output of around 30W. As a request from the community, two more output channels were added. A 4 pin connector, exposing an I2C BUS is now available as well. It might be used for hardware extensions.

- [x] Test the new boards once they arrive
- [x] Analyze the level-shifted data signal
- [x] Test the I2C BUS
- [x] Test the dual regulator setup
- [x] Adjust the software to support two more channels
- [ ] ~~Close #37 before closing this issue~~
- [x] Close #38 before closing this issue

Closed 2022-11-07.

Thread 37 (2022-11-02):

Design a new case for the upgraded hardware

TheRealKasumi, 2022-11-02:
In #36 we want to introduce a new hardware version. Since the board dimensions changed, a new case should be designed to properly fit it.

- [x] Once the boards are there, design a new case
- [x] Make sure it can easily be 3D printed
- [x] Provide it as stl file(s)

Closed 2022-12-22.

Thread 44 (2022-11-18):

Hardware 2.1

TheRealKasumi, 2022-11-18:
With the hardware update 2.1 the following features should be introduced.

- Upgraded board design
- Fan control
- Temperature sensors
- Temperature check of regulators
- Reduce brightness when reacahing a high temperature
- Values configurable in the UI
- Implementation of the BH1750 light sensor
<br>

- [x] Implement fan controller
- [X] Implement temperature sensor
- [x] Implement overheat protection
- [X] Make it configurable via the UI
- [x] Update documentation
- [x] More hardware abstraction
- [x] Implementation of the BH1750 light sensor
- [x] Test the chaos you created...

Closed 2022-11-20.

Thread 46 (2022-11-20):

Alternatives to turn on/off TesLight

TheRealKasumi, 2022-11-20:
Currently there are two ways to turn on/off the LEDs with TesLight. This is by measuring the voltage of the footwell lights or by using a BH1750 light sensor which can be plugged into the I2C connector. Since some Teslas don't have the footwell lighting, it would be good to have alternatives.

- [x] Try if the motion sensor can be used
- [x] Try if Bluetooth could be an option (for example detecting the phone)

TheRealKasumi, 2022-12-02:
Identifying a mobile device via it's bluetooth MAC address doesn't really work in these days. Most devices seem to use MAC address randomization. So a connection to the device would be required. This again would require an app which is running on the mobile device to communicate with the BLE device (TesLight). Since there currently is no mobile app for this, it's hard to achieve. That's why this was put on pause and focus was set on the motion sensor instead.

Closed 2022-12-02.

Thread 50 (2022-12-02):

Save motion sensor calibration to configuration

TheRealKasumi, 2022-12-02:
Calibrating the motion sensor at each start of the controller is not the best solution. When the car is not parked on an even ground, this can lead to miscalibration. To solve this issue, the calibration should be saved to the configuration and a recalibration via the UI should be possible.

- [x] Save the calibration data to the configuration
- [x] Only calibrate the sensor when no calibration data exists or the user is triggering the calibration via the UI

Closed 2022-12-03.

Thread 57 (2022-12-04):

Part List: Add Symphony Stripes

JakobLichterfeld, 2022-12-04:

JakobLichterfeld, 2022-12-04:
These LED wires a very small and are masked with black foil and are thus dimmed, which is great as we can use the full color spectrum of the LEDs and at the same time do not get blind while driving.
https://de.aliexpress.com/item/1005004297563628.html

JakobLichterfeld, 2022-12-05:
> Oh, this just came to my mind. In case these are added we should also add a note to check the polarity beforehand. We had a case where the wire colors were swapped see_no_evil .

Yeah, this is already in Build Guide, see [here](https://github.com/TheRealKasumi/TesLight/blob/d86f316d2efecdc81aca7dbdadb4e40b64f8cc10/documentation/build.md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). But we can add an enhanced polarity check as well.

JakobLichterfeld, 2022-12-05:
More enhanced Polarity guide:

The middle cable (green?) should always be data. Then plug one cable to GND and connect the other one with a 220 Ohm resistor to 5 V. If the strip turns on, then everything is good. If not, try the other way around. There should be no current flowing through the resistor high enough to damage the strip.

We assume the following wiring:
red = 5 V
green = data
blue = GND

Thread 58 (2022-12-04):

Part List: Add recommended length

JakobLichterfeld, 2022-12-04:
For Tesla Model 3:

| Location | length of LED stripe |
| ------------- | ------------- |
| Front Doors top MY 2019 | 100 cm, and shorten about 10 cm  |
|  Rear Doors top | 75 cm, and shorten a bit  |
| Front and Rear Doors around handle | 100 cm  |
| Dashboard | 130 cm, connect 2* 75 cm in series and shorten a bit  |
| Center console MY2019 | Fibre Wire, tbd LED stripe |
| Center console MY2021 | Fibre Wire, tbd LED stripe |

Closed 2022-12-09.

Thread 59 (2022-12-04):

Documentation: How to position the board in the vehicle for correct acceleration directions of the sensor values

JakobLichterfeld, 2022-12-04:
It would be best if the antenna of the ESP32 points to the front and the USB port to the back of the vehicle. This way we ensure consistent acceleration directions from the sensor for all users.

TheRealKasumi, 2022-12-04:
Good that you pointed this out again 😋 . I guess otherwise it would get lost in the TFF-Thread at some point.

Closed 2022-12-09.

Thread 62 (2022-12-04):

Documentation: Build: How to get the signal of the factory build footwell lights without any harm

JakobLichterfeld, 2022-12-04:
Use an "electricity thief" to get the signal of the factory build Footlights. You can even use [this T-connector](https://www.amazon.de/dp/B07F3SGJXR).

It could look like this if you add the correct plugs.
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

TheRealKasumi, 2022-12-04:
Looking very good. I would really like to add this. Where is the extension with the connectors from?

JakobLichterfeld, 2022-12-04:
Picture ist not mine, I will add part numbers and add it to the part list.

JakobLichterfeld, 2022-12-05:
The connectors for the LEDs on the Model 3 are these:
A) [Female Connector 35](https://www.mouser.com/ProductDetail/TE-Connectivity-AMP/1534111-1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) (car uses this) - TE Connectivity / AMP P/N: 1534111-1
B) [Male Connector 8](https://www.mouser.com/ProductDetail/571-1-1534155-1) (LED’s use this) - TE Connectivity / AMP P/N: 1-1534155-1
AB) [Retainer / Cover for Connectors 4](https://www.mouser.com/ProductDetail/571-1534027-1) (each connector needs one) - TE Connectivity / AMP P/N: 1534027-1
C) [Pin Connectors 5](https://www.mouser.com/ProductDetail/571-1-928918-1-CT) (2 per plug) - TE Connectivity / AMP P/N: 1-928918-1 (Cut Strip)

Source: [https://teslamotorsclub.com/tmc/posts/3974791/ 16](https://teslamotorsclub.com/tmc/posts/3974791/)

Closed 2022-12-09.

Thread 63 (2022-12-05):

Documentation: Planning: correct length of wire

JakobLichterfeld, 2022-12-05:
I know I wrote this myself. Not looking at it again I feel like 5m is a lot. Wonder why I wrote it back then. Probably because of the lengths that are available on Amazon. Maybe we should check again if we can get away with less waste.

_Originally posted by @TheRealKasumi in https://github.com/TheRealKasumi/TesLight/pull/52#discussion_r1039021728_

Closed 2022-12-09.

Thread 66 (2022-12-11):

Bug: Cache disabled but cached memory region accessed

TheRealKasumi, 2022-12-11:
I recently experienced different, randomly appearing crashes like:

```
Guru Meditation Error: Core  1 panic'ed (Cache disabled but cached memory region accessed).

Core  1 register dump:
PC      : 0x4011b968  PS      : 0x00060035  A0      : 0x800814ae  A1      : 0x3ffbf1fc
A2      : 0x00000002  A3      : 0x00000001  A4      : 0xbad00bad  A5      : 0x00000000
A6      : 0x00000006  A7      : 0x00000000  A8      : 0x8011b963  A9      : 0x3ffbf1dc
A10     : 0x00000001  A11     : 0xffffffff  A12     : 0x000f8023  A13     : 0x00000006
A14     : 0x007bf2a8  A15     : 0x00000000  SAR     : 0x0000000f  EXCCAUSE: 0x00000007
EXCVADDR: 0x00000000  LBEG    : 0x00000000  LEND    : 0x00000000  LCOUNT  : 0x00000000

Backtrace:0x4011b965:0x3ffbf1fc |<-CORRUPTED

  #0  0x4011b965:0x3ffbf1fc in xPortEnterCriticalTimeoutSafe at /Users/ficeto/Desktop/ESP32/ESP32S2/esp-idf-public/components/freertos/port/xtensa/include/freertos/portmacro.h:590
      (inlined by) vPortEnterCriticalSafe at /Users/ficeto/Desktop/ESP32/ESP32S2/esp-idf-public/components/freertos/port/xtensa/include/freertos/portmacro.h:599
      (inlined by) rmt_set_tx_intr_en at /Users/ficeto/Desktop/ESP32/ESP32S2/esp-idf-public/components/driver/rmt.c:497
```

```
Guru Meditation Error: Core  1 panic'ed (Cache disabled but cached memory region accessed).

Core  1 register dump:
PC      : 0x4011bae0  PS      : 0x00060035  A0      : 0x800817f2  A1      : 0x3ffbf22c
A2      : 0x3ffc3220  A3      : 0x00000002  A4      : 0x0ffd114c  A5      : 0xfffffffe
A6      : 0x0000001a  A7      : 0x00000008  A8      : 0x800813d5  A9      : 0x00000008
A10     : 0x00000002  A11     : 0x00000000  A12     : 0x00000010  A13     : 0x00000000
A14     : 0x00000003  A15     : 0x00060323  SAR     : 0x00000012  EXCCAUSE: 0x00000007
EXCVADDR: 0x00000000  LBEG    : 0x00000000  LEND    : 0x00000000  LCOUNT  : 0x00000000

Backtrace:0x4011badd:0x3ffbf22c |<-CORRUPTED

  #0  0x4011badd:0x3ffbf22c in rmt_set_tx_thr_intr_en at ??:?
```

```
Guru Meditation Error: Core  1 panic'ed (Cache disabled but cached memory region accessed).

Core  1 register dump:
PC      : 0x4011b92c  PS      : 0x00060035  A0      : 0x800817f2  A1      : 0x3ffbf22c
A2      : 0x3ffc3080  A3      : 0x0028800a  A4      : 0x0ffd114c  A5      : 0xfffffffe
A6      : 0x0000001a  A7      : 0x00000008  A8      : 0x800814ae  A9      : 0x3ffbf20c
A10     : 0x00000002  A11     : 0x00000001  A12     : 0x3ff56ac8  A13     : 0x00000000
A14     : 0x00000006  A15     : 0x00000000  SAR     : 0x00000007  EXCCAUSE: 0x00000007
EXCVADDR: 0x00000000  LBEG    : 0x00000000  LEND    : 0x00000000  LCOUNT  : 0x00000000

Backtrace:0x4011b929:0x3ffbf22c |<-CORRUPTED

  #0  0x4011b929:0x3ffbf22c in rmt_module_enable at /Users/ficeto/Desktop/ESP32/ESP32S2/esp-idf-public/components/driver/rmt.c:130
```

I have no clue at the moment, why this is happening, what exactly is causing it and how to fix it. But we need to do something about this otherwise I see the project at risk. ~~Unfortunately, I can't provide any code that is constantly reproducing it.~~ [click](https://github.com/TheRealKasumi/TesLight/tree/bug/cache-disable-but-chached-memory-region-accessed). Using WiFi in `STA` mode seems to trigger it more frequently. Same for using the `Os` optimization flag. Also, it seems to be related to the `rmt` driver. At least it can be found in almost every stack trace.

Maybe related, but should be fixed in the meantime: https://github.com/espressif/esp-idf/issues/9487

TheRealKasumi, 2023-02-05:
Closing this issue with #141 since it potentially disapeared with the new LED driver.

Closed 2023-02-05.

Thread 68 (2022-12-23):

Switch to json based API

TheRealKasumi, 2022-12-23:
Based on a few experiments I think we can switch to a json based API.

- [x] Implement json based API
- [x] OpenAPI document
- [x] Swagger
- [x] Test if it works
- [x] Test if memory is a issue

Closed 2022-12-24.

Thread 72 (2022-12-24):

Model: 0.8 mm wall thickness detected

JakobLichterfeld, 2022-12-24:
In the TesLight_Case and TesLight_Fan_Adapter there are 0.8mm wall thickness detected by jlcpcb.
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

JakobLichterfeld, 2022-12-24:
@rgrae81 can look into this?

rgrae81, 2022-12-24:
Fan-Adapter has such thin walls but this should be no problem to print.
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

at the case it should also be related to the fan.
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

Normally this is not a problem to print. Didn't know tha jlcpcb marks warnings here.

JakobLichterfeld, 2022-12-24:
Thanks for quick response. I already did ask them to continue the print. If it ran through successful, I will add a short description in build documentation about this.

JakobLichterfeld, 2023-01-09:
3 D Print in Selective Laser Sintering (SLS) - Nylon from [jlcpcb.com](jlcpcb.com) looks great, no issues found
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

Closed 2023-01-09.

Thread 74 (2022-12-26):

Adjust cable lengths (dashboard, front doors), each 50 cm shorter

PhilippDenn, 2022-12-26:
The cable length for dashboard and front doors should be 50cm shorter for the Model 3. This makes the cable management easier.

- [ ] Adjust the cable length in the documentation

Closed 2022-12-29.

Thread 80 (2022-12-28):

Lower Fan Temp limit not adjustable below 45 °C

PhilippDenn, 2022-12-28:
**To Reproduce**
Steps to reproduce the behavior:
1. Go to Settings
2. Adjust Fan Start Temp to less than 45 °C
3. Apply Settings
4. See error

**Screenshots**
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

**Information:**
 - Device: iPad Mini 5
 - Browser Safari

JakobLichterfeld, 2022-12-29:
https://github.com/TheRealKasumi/TesLight/blob/86004bc481b642a0e2173e348b9d2414062a8ada/mcu/include/configuration/SystemConfiguration.h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

Closed 2022-12-29.

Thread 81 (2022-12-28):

"Fan on" button

PhilippDenn, 2022-12-28:
A simple button for switching the fan on (full power or adjustable) regardless of the temperature

JakobLichterfeld, 2022-12-29:
Can you add some context about situations where you need it? Is this meant for testing purpose?

PhilippDenn, 2022-12-29:
To make people happy like my dad who thinks all electronics start burning at 60 degrees 😂

danielbayerlein, 2022-12-29:
@TheRealKasumi Would it be possible to control this feature via the existing Fan Start Temp setting?

TheRealKasumi, 2022-12-30:
Should be pretty easy to do. Who ever takes this (probably me), we could rework the fan controller a bit. Maybe introduce an enum `FanMode` with `ALWAYS_OFF`, `ALWAYS_ON` and `AUTO`. This then also needs to be written to the configuration file.

@danielbayerlein Would be possible by setting the starting temp to 0 and the max temp to 1 for example. However I would propose to implement it properly. We could also allow the user to set the fan speed when its always on.

Closed 2023-01-21.

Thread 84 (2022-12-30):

Create endpoint exposing system and hardware information

TheRealKasumi, 2022-12-30:
Like discussed earlier it would be interesting to have an endpoint that is exposing some system information. Also with the new audio analyzer we are bringing more optinal hardware into the project. With this, some features might not be available for everyone. Having a list of available hardware, the UI can hide unavailable settings and options.

- [ ] Collect system and hardware information inside a `SystemInformation` class
- [ ] Include: RPS, FPS, power consumption, temps, fan, memory usage
- [ ] Collect information about available hardware: Audio analyzer, BH1750, MPU6050 (yes we can make it optional with that step), installed regulators

Closed 2023-01-20.

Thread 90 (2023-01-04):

Documentation: Clarify luminant type and lenght infos in plan document

MathiasSeifert, 2023-01-04:
Add some additional details about the different types of luminants (led strip, fiber tube, light bar), advantages and disadvantages and the recommended default setup.
Restructure the tables for zone config and light bar lengths to have all length information (cable and luminant) in one table.

Closed 2023-01-19.

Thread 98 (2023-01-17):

Bug: Stale LEDs when reducing LED count

MathiasSeifert, 2023-01-17:
**Describe the bug**
When reducing the LED count in the UI below the number of LEDs on the strip, then the "extra" LEDs remain at their last status instead of being turned off.

**To Reproduce**
Steps to reproduce the behavior:
1. Turn on the light on any zone, make sure all LEDs are lit up
3. Go to 'Advanced' in the zone configuration and reduce the 'LED Count' to a number that is smaller the the actual count of LEDs in that zone.
4. Click 'Apply Settings'
5. Observe that the LEDs above the LED count are still lighting.

**Expected behavior**
When changing the LED Count any LED on the strip that is above the count should be turned off.

**Additional context**
The 'Average Power' that is printed on the console is also affected by this, as it only calculates the power based on the configured LEDs, not the actually lit up LEDs

TheRealKasumi, 2023-02-04:
This is fixed for the maximum supported number of LED with the new LED driver. See https://github.com/TheRealKasumi/TesLight/pull/141. Problem in theory is still valid for unsupported high numbers of LEDs per zone (>250). But we cant output "off" to an infinite number of LEDs. I guess thats fair.

Closed 2023-02-05.

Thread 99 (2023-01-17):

Documentation: Add Software Installation Documentation

MathiasSeifert, 2023-01-17:
Create documentation that describes how to flash the release binaries onto the ESP32 and how to prepare the SD card with the release UI archive .

MathiasSeifert, 2023-01-17:
Some info for reference in case it is ever needed again (all for board az-delivery-devkit-v4):
Bootloader binaries download:
https://github.com/espressif/arduino-esp32/blob/2.0.5/tools/sdk/esp32/bin/bootloader_dio_40m.bin
https://github.com/espressif/arduino-esp32/blob/2.0.5/tools/partitions/boot_app0.bin

esptool download:
https://github.com/espressif/esptool/releases / https://github.com/espressif/esptool/releases/download/v4.4/esptool-v4.4-win64.zip

esptool flash command (update com port number and bin file paths as needed):
esptool.exe --chip esp32 --port "COM5" --baud 460800 --before default_reset --after hard_reset write_flash -z --flash_mode dio --flash_freq 40m --flash_size 4MB 0x1000 bootloader_dio_40m.bin 0x8000 partitions.bin 0xe000 boot_app0.bin 0x10000 firmware.bin

Closed 2023-01-17.

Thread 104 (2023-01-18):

Bug: TesLight UI would not start using the added "homescreen app" when using iOS/iPad OS

PhilippDenn, 2023-01-18:
**Added Homescreen Icon does not work on iOS**

**To Reproduce**
Steps to reproduce the behavior:
1. Go to the TesLight UI in safari
2. Click on 'the upfacing arrow'
3. Scroll down to 'to homescreen/Zum Home-Bildschirm'
4. Add (the address cannot be changed and therefore there is an addition (from the opened TeslLight Ui) and not the IP itself)
5. Try to start the "TesLight app"
6. UI will not start

**Expected behavior**
UI should start

**Screenshots**
I will add them later, sorry my TesLight board is not in reach at the moment.

**Information:**
 - Device: iPhone 13 Pro Max, iPad Mini 5
 - OS: iOS 16.2; iPad OS
 - Browser Safari

**Additional context**
When opening the IP of TesLight during flight mode, the UI will not start (as expected). If you than add the bare IP to the homescreen, the UI will start, but the icon on the homescreen will not appear.

PhilippDenn, 2023-01-23:
The "TesLight App" try's to open the following page:

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

By using the "App Icon" only a white screen appears

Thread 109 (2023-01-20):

Only show available hardware-based options in the ui

TheRealKasumi, 2023-01-20:
With #107 we add a new endpoint that allowed to query advanced information about teslights software and hardware. This especially includes optional hardware, that can be connected to the controller. The UI should only show hardware-based options when the required hardware is available. So for example when the MPU6050 is missing, there should be no motion based effects selectable.

- [x] Implement in frontend

danielbayerlein, 2023-01-20:
@TheRealKasumi Can you please describe each option?

TheRealKasumi, 2023-01-20:
Its relatively simple. When you query the new `/api/info/system` endpoint, you will receive a response like this:

```
{
    "socInfo": {...},
    "hardwareInfo": {
        "hwVersion": "2.1",
        "regulatorCount": 2,
        "regulatorVoltage": 5,
        "regulatorCurrentLimit": 6,
        "regulatorCurrentDraw": 0.056253076,
        "regulatorPowerLimit": 24,
        "regulatorPowerDraw": 0.281265378,
        "regulatorTemperature": 70,
        "fanSpeed": 255,
        "mpu6050": 1,
        "ds18b20": 0,
        "bh1750": 0,
        "audioUnit": 0
    },
    "tlSystemInfo": {...}
}
```

Most of this is just nice to have information that we can display in the expert mode later. However the last 4 properties are interesting for you. They tell you how many sensors of a specific type are connected. So if the mpu6050 is `>0`, this means you can display all settings that use the motion sensor. These are the  motion based animations and the "power mode" with the mpu6050.

Same applies for the bh1750 which is the light sensor. The one that can actually measure the enviornment brightness. If this one is not connected, we should not have it available in the ui as "power mode".

The audio unit is not relevant yet but is coming very soon.

ds18b20 tells you how many temperature sensors are connected. This might be interesting to maybe show a warning when the automatic fan mode is selected (#114). When its not available the fan speed will be always at 100% when automatic is selected.

Does that help?

Closed 2023-01-22.

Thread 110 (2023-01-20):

bug: only update wifi config when it was changed

TheRealKasumi, 2023-01-20:
Currently the WiFi config is updated every time the settings are save. Creating a ap with the same ssid and passwort creates an error in the mcu. Settings should only be updated when actually changed.

Closed 2023-01-20.

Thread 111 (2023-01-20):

Copy configuration from one zone to other zones

TheRealKasumi, 2023-01-20:
It can be quite annoying to configure each zone individually. It would be very helpful if configurations could be copied to another zone. For example from the left to the right door.

danielbayerlein, 2023-01-20:
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

TheRealKasumi, 2024-06-02:
@Weberan89 implemented something similar in [feat/ui_add_submit2all](https://github.com/TheRealKasumi/NikoLight/tree/feat/ui_add_submit2all). Maybe we can combine both ideas 👍 .

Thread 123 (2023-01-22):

Merge duplicated effects

TheRealKasumi, 2023-01-22:
We currently have duplicated effects like the `RainbowAnimator` and `RainbowAnimatorMotion` that use basically identical code.

- [ ] Try to merge them
- [ ] Use the custom field `Sensor Value` to determine the type (random, motion, audio...)

Dicuss with @danielbayerlein

TheRealKasumi, 2024-06-02:
I will close this issue since it was already done during my work on an upcoming firmware release.

Closed 2024-06-02.

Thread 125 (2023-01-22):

Adjust ui for new dataSource property and audio based sparkle

TheRealKasumi, 2023-01-22:
With #122 the audio based sparkle animation will be implemented. To keep the code clean, some small adjustment to the LED api were done. Now there is a new `dataSource` field in the LED configuration. It will take the role of the custom field for selecting the motion axis. For this a new enum was introduced. It can contain any data source now, instead of only MPU6050 based value.

```
enum class DataSource : uint8_t
{
	DS_NONE = 0,					           // No data source, animator is providing the data itself
	DS_RANDOM = 1,					   // Random data is used for the animation
	DS_ACC_X_RAW = 2,				   // Raw x acceleration is used for the animation
	DS_ACC_Y_RAW = 3,				   // Raw y acceleration is used for the animation
	DS_ACC_Z_RAW = 4,				   // Raw z acceleration is used for the animation
	DS_GY_X_RAW = 5,				           // Raw x rotation is used for the animation
	DS_GY_Y_RAW = 6,				           // Raw y rotation is used for the animation
	DS_GY_Z_RAW = 7,				           // Raw z rotation is used for the animation
	DS_ACC_X_G = 8,					   // Acceleration on x axis in g is used for the animation
	DS_ACC_Y_G = 9,					   // Acceleration on y axis in g is used for the animation
	DS_ACC_Z_G = 10,				           // Acceleration on z axis in g is used for the animation
	DS_GY_X_DEG = 11,				   // Rotation around the x axis in deg/s is used for the animation
	DS_GY_Y_DEG = 12,				   // Rotation around the y axis in deg/s is used for the animation
	DS_GY_Z_DEG = 13,				   // Rotation around the z axis in deg/s is used for the animation
	DS_PITCH = 14,					   // Pitch angle of the unit is used for the animation
	DS_ROLL = 15,					   // Roll angle of the unit is used for the animation
	DS_YAW = 16,					           // Yaw angle of the unit is used for the animation
	DS_ROLL_COMPENSATED_ACC_X_G = 17,  // Roll angle compensated acceleration on x axis in g is used for the animation
	DS_PITCH_COMPENSATED_ACC_Y_G = 18, // Pitch angle compensated acceleration on y axis in g is used for the animation
	DS_AUDIO_FREQUENCY_TRIGGER = 19,     // Frequency triggers of the audio unit are used for the animation
	DS_AUDIO_FREQUENCY_VALUE = 20,	   // Frequency value of the audio unit are used for the animation
	DS_AUDIO_VOLUME_PEAK = 21		   // Volume peak of the audio unit are used for the animation
};
```

For now we keep the separation beween "normal" and "motion" animations. This will be done in #123 . However to select the axis for motion based effects, the `dataSource` should now be used. The old custom field can be removed.

For the sparkle animator there should be a new dropdown to switch between data source `DS_RANDOM` and `DS_AUDIO_FREQUENCY_TRIGGER`. Also a bit mask for selecting the frequency bands should be implemented.

Example: 0B10000000 -> only band 1; 0B01000000 -> only band 2; 0B11000000 -> band 1 and band 2 ect

Closed 2023-01-27.

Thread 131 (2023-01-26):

Documentation and FrontEnd: TesLight is now TesLight®

PhilippDenn, 2023-01-26:
TesLight is now a registered german brand 🎉

So now the small R ® can be added everywhere ☺️ in the doch and in the app itself!

This will have no changes for private and friendly use of TesLight®!

Closed 2023-01-27.

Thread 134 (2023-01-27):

Animation stuttering every ~500ms

TheRealKasumi, 2023-01-27:
I assume this happens when reading the temperature sensors since they are quite slow and blocking the controller. To be checked.

TheRealKasumi, 2023-03-05:
This is indeed a problem with the temperature sensor. There are two options.

1. We introduce multithreading to "fix" this issue
2. We use a load based approach for the fan control

In the long term I would like to combine both. So have a load based fan control and multithreading with a low sample rate of the temperature sensor. This gives us more safety.

The second point is already in progress. For multithreading I need more time than I currently have to do it properly.

TheRealKasumi, 2024-06-02:
I can say by now that this issue is kind of unfixable. Reading out the temperature sensors will always block the LED thread or the sensor thread since it is necessary to disable interrupts on one CPU core for this time. This would also prevent the task scheduler to run a different task on the same CPU. Because of that, I have no solution to fix the issue.

However, there will be a workaround in the next firmware release. The DS18B20 temperature sensors will be disabled (but can still be used if the user expliciltly wants to do that) and a new algorithm will be used for the fan control. It will be based on the load of the regulators.

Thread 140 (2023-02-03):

Create own LED driver and remove FastLED lib

TheRealKasumi, 2023-02-03:
FastLED brought us a lot of random bugs, errors and crashes that do not happen without it. So I decided to write down our own LED driver.

- [x] Use I2S
- [x] Should be memory efficient
- [x] Should be fast and drive 1600 (200 per zone) without a problem
- [x] Check stability and make sure its safe to use with webserver and multiple tasks

Closed 2023-02-05.

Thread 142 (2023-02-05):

Add link to the project files of the case

TheRealKasumi, 2023-02-05:
@rgrae81 kindly provided us a link to the project files of the 3D Models. They can be found [here](https://www.tinkercad.com/things/jYiaTRrcGH9?sharecode=eO4PPUE9WJDS8Cvu4xWAiNseFuMdvLwx1j_lV1GVKRw). It would be good if we can add it to the documentation. Proposal: maybe around the section of ordering the PCB/3D print???

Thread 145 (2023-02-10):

Implement Audio Unit configuration in UI

TheRealKasumi, 2023-02-10:
Sorry for openening another UI ticket🤣... I was a little worried we miss this. There are endpoints to configure the audio unit. These settings should also be brought to the ui at some point.

TheRealKasumi, 2024-06-02:
Closing this issue as this will not be relevant in the future. The NikoLight MCU will not confugre any parameters of the Audio Unit starting from the upcoming version. Instead, the Audio Unit will provide its own configuration UI together with live data to provide a better user experience.

The repository of the Audio Unit is currently not public. However, I will keep track of this since I'm actively working on the new AU FW.

Closed 2024-06-02.

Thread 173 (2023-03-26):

Make the project GPLv3

TheRealKasumi, 2023-03-26:
I would like to put this project under the GPLv3 license. Let’s discuss and eventually do so.

Opinions @danielbayerlein @JakobLichterfeld @MathiasSeifert @rgrae81 @heyitsmarlon ?

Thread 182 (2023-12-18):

Issue with iOS "Add to Homescreen"

heyitsmarlon, 2023-12-18:
**Describe the bug**
When a bookmark is added to the home screen on iOS the URL set by the manifest.json is "https://192.168.4.1/ui/" which somehow redirects to "https://192.168.4.1/ui/index.htm" instead of "https://192.168.4.1/ui/index.html".

To fix this problem the manifest.json can be modified to set the correct URL on a bookmark.

**Information:**
 - Device: iPhone 12
 - OS: iOS 17.2
 - Browser safari

Closed 2024-03-16.

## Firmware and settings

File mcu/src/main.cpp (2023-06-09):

/**
 * @file main.cpp
 * @author TheRealKasumi
 * @brief Entry point, initialization and main loop of the program.
 *
 * @copyright Copyright (c) 2023 TheRealKasumi
 *
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
 */
#include "NikoLight.h"

/**
 * @brief Initialize the software and hardware.
 */
void setup()
{
	NikoLight::begin();
}

/**
 * @brief Main loop runs as long as the controller is active.
 */
void loop()
{
	NikoLight::run();
}

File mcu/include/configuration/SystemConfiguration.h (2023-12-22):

/**
 * @file SystemConfiguration.h
 * @author TheRealKasumi
 * @brief Contains the (static) system configuration.
 *
 * @copyright Copyright (c) 2023 TheRealKasumi
 * 
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
 */
#ifndef SYSTEM_CONFIGURATION_H
#define SYSTEM_CONFIGURATION_H

// Version configuration
#define FW_VERSION "1.1.0" // Firmware version of the MCU
#define HW_VERSION_2_1     // Hardware version (HW_VERSION_1_0, HW_VERSION_2_0, HW_VERSION_2_1, HW_VERSION_2_2 [!experimental!])

#if defined(HW_VERSION_1_0)
	#define HW_VERSION "1.0"
#elif defined(HW_VERSION_2_0)
	#define HW_VERSION "2.0"
#elif defined(HW_VERSION_2_1)
	#define HW_VERSION "2.1"
#elif defined(HW_VERSION_2_2)
	#define HW_VERSION "2.2"
#else
	#error "A valid hardware version must be defined."
#endif

// SD configuration
#define SD_CS_PIN 5			 // CS pin for the SD card
#define SD_SPI_SPEED 4000000 // SPI data rate
#define SD_MOUNT_POINT "/sd" // Mount point for the SD card
#define SD_MAX_FILES 5		 // Maximum number of open files

// Logging configuration
#define SERIAL_BAUD_RATE 115200			// Serial baud rate
#define LOG_FILE_NAME "/system_log.txt" // File name of the log file
#define LOG_DEFAULT_LEVEL 1 			// Default log level

// Configuration of the runtime configuration
#define CONFIGURATION_FILE_VERSION 14		  // Version of the configuration file
#define CONFIGURATION_FILE_NAME "/config.nli" // File name of the configuration file
#define CONFIGURATION_MAX_PROFILES 50		  // Maximum number of profiles

// LED and effect configuration
#define LED_NUM_ZONES 8 											  // Number of LED zones
#if defined(HW_VERSION_1_0)											  // Pin mapping of zones to physical pins depending on hardware version
	#define LED_DEFAULT_OUTPUT_PINS {13, 14, 15, 16, 17, 21, 22, 25}
#elif defined(HW_VERSION_2_0)
	#define LED_DEFAULT_OUTPUT_PINS {13, 17, 14, 21, 15, 22, 16, 25}
#elif defined(HW_VERSION_2_1)
	#define LED_DEFAULT_OUTPUT_PINS {13, 14, 15, 16, 17, 21, 22, 25}
#elif defined(HW_VERSION_2_2)
	#define LED_DEFAULT_OUTPUT_PINS {4, 12, 13, 14, 15, 16, 17, 21}
#endif
#define LED_DEFAULT_COUNTS {2, 2, 2, 2, 2, 2, 2, 2}					  // Default number of LEDs for each channel
#define LED_DEFAULT_CHANNEL_CURRENT 16 								  // Default current per LED channel in mA
#define LED_MAX_COUNT_PER_ZONE 250									  // Maximum number of LEDs per channel
#define ANIMATOR_NUM_ANIMATION_SETTINGS 25  						  // Number of custom fields in the LED configuration
#define ANIMATOR_DEFAULT_TYPE 0		   								  // Default animation type
#define ANIMATOR_DEFAULT_DATA_SOURCE 0								  // Default data source of the animation
#define ANIMATOR_DEFAULT_SPEED 50	   								  // Default animation speed
#define ANIMATOR_DEFAULT_OFFSET 10	   								  // Default animation offset
#define ANIMATOR_DEFAULT_BRIGHTNESS 50 								  // Default zone brightness
#define ANIMATOR_DEFAULT_REVERSE false 								  // Default reversal of the animation
#define ANIMATOR_DEFAULT_FADE_SPEED 30 								  // Default fading speed
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

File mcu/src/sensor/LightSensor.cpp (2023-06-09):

/**
 * @file LightSensor.cpp
 * @author TheRealKasumi
 * @brief Implementation of the {@link NL::LightSensor}.
 *
 * @copyright Copyright (c) 2023 TheRealKasumi
 *
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
 */
#include "sensor/LightSensor.h"

bool NL::LightSensor::initialized = false;
float NL::LightSensor::lastBrightnessValue;
NL::MotionSensor::MotionSensorData NL::LightSensor::motionData;
unsigned long NL::LightSensor::motionSensorTriggerTime;

/**
 * @brief Start the light sensor.
 * @return OK when the light sensor was initialized
 * @return ERROR_CONFIG_UNAVAILABLE when the configuration is not available
 */
NL::LightSensor::Error NL::LightSensor::begin()
{
	NL::LightSensor::initialized = false;
	if (!NL::Configuration::isInitialized())
	{
		return NL::LightSensor::Error::ERROR_CONFIG_UNAVAILABLE;
	}

	NL::LightSensor::lastBrightnessValue = 0.0f;
	NL::LightSensor::motionData.accXRaw = 0;
	NL::LightSensor::motionData.accYRaw = 0;
	NL::LightSensor::motionData.accZRaw = 0;
	NL::LightSensor::motionData.gyroXRaw = 0;
	NL::LightSensor::motionData.gyroYRaw = 0;
	NL::LightSensor::motionData.gyroZRaw = 0;
	NL::LightSensor::motionData.accXG = 0.0f;
	NL::LightSensor::motionData.accYG = 0.0f;
	NL::LightSensor::motionData.accZG = 0.0f;
	NL::LightSensor::motionData.gyroXDeg = 0.0f;
	NL::LightSensor::motionData.gyroYDeg = 0.0f;
	NL::LightSensor::motionData.gyroZDeg = 0.0f;
	NL::LightSensor::motionData.pitch = 0.0f;
	NL::LightSensor::motionData.roll = 0.0f;
	NL::LightSensor::motionData.yaw = 0.0f;
	NL::LightSensor::motionData.rollCompensatedAccXG = 0.0f;
	NL::LightSensor::motionData.pitchCompensatedAccYG = 0.0f;
	NL::LightSensor::motionData.temperatureRaw = 0;
	NL::LightSensor::motionData.temperatureDeg = 0;
	NL::LightSensor::motionSensorTriggerTime = millis();

	NL::LightSensor::initialized = true;
	return NL::LightSensor::Error::OK;
}

/**
 * @brief Stop the light sensor.
 */
void NL::LightSensor::end()
{
	NL::LightSensor::initialized = false;
}

/**
 * @brief Check if the light sensor is initialized.
 * @return true when initialized
 * @return false when not initialized
 */
bool NL::LightSensor::isInitialized()
{
	return NL::LightSensor::initialized;
}

/**
 * @brief Return the LED brightness based on the sensors mode and the environment.
 * @param brightness 0.0 for minimum brightness up to 1.0 for maximum brightness
 * @return OK when the brightness was calculated
 * @return ERROR_ADC_UNAVAILABLE when the ADC is not available
 * @return ERROR_BH1750_UNAVAILABLE when the BH1750 is not available
 * @return ERROR_MPU6050_UNAVAILABLE when the MPU6050 is not available
 * @return ERROR_UNKNOWN_MODE when the light sensor mode is invalid
 */
NL::LightSensor::Error NL::LightSensor::getBrightness(float &brightness)
{
	brightness = NL::LightSensor::lastBrightnessValue;
	const NL::LightSensor::Error error = NL::LightSensor::getBrightnessInt(brightness);
	NL::LightSensor::lastBrightnessValue = brightness;
	return error;
}

/**
 * @brief Return the brightness of the lights based on the sensors mode.
 * @param brightness 0.0 for minimum brightness up to 1.0 for maximum brightness
 * @return OK when the brightness was calculated
 * @return ERROR_ADC_UNAVAILABLE when the ADC is not available
 * @return ERROR_BH1750_UNAVAILABLE when the BH1750 is not available
 * @return ERROR_MPU6050_UNAVAILABLE when the MPU6050 is not available
 * @return ERROR_UNKNOWN_MODE when the light sensor mode is invalid
 */
NL::LightSensor::Error NL::LightSensor::getBrightnessInt(float &brightness)
{
	const NL::Configuration::SystemConfig systemConfig = NL::Configuration::getSystemConfig();
	const float antiFlickerThreshold = 0.002f;
	const NL::LightSensor::LightSensorMode lightSensorMode = (NL::LightSensor::LightSensorMode)systemConfig.lightSensorMode;
	const float threshold = systemConfig.lightSensorThreshold / 255.0f;
	const float minAmbientBrightness = systemConfig.lightSensorMinAmbientBrightness / 255.0f;
	const float maxAmbientBrightness = systemConfig.lightSensorMaxAmbientBrightness / 255.0f;
	const float minLedBrightness = systemConfig.lightSensorMinLedBrightness / 255.0f;
	const float maxLedBrightness = systemConfig.lightSensorMaxLedBrightness / 255.0f;
	const uint8_t duration = systemConfig.lightSensorDuration;

	// Always off
	if (lightSensorMode == NL::LightSensor::LightSensorMode::ALWAYS_OFF)
	{
		brightness = 0.0f;
		return NL::LightSensor::Error::OK;
	}

	// Always on
	else if (lightSensorMode == NL::LightSensor::LightSensorMode::ALWAYS_ON)
	{
		brightness = 1.0f;
		return NL::LightSensor::Error::OK;
	}

	// Auto on/off using ADC
	else if (lightSensorMode == NL::LightSensor::LightSensorMode::AUTO_ON_OFF_ADC)
	{
		if (!NL::AnalogInput::isInitialized())
		{
			brightness = 1.0f;
			return NL::LightSensor::Error::ERROR_ADC_UNAVAILABLE;
		}

		float value = 0.0f;
		for (uint8_t i = 0; i < 10; i++)
		{
			value += NL::AnalogInput::getAnalogVoltage() / 3.3f;
		}
		value /= 10.0f;

		if (value > threshold + antiFlickerThreshold)
		{
			brightness = 1.0f;
		}
		else if (value < threshold - antiFlickerThreshold)
		{
			brightness = 0.0f;
		}

		return NL::LightSensor::Error::OK;
	}

	// Auto brightness using ADC
	else if (lightSensorMode == NL::LightSensor::LightSensorMode::AUTO_BRIGHTNESS_ADC)
	{
		if (!NL::AnalogInput::isInitialized())
		{
			brightness = 1.0f;
			return NL::LightSensor::Error::ERROR_ADC_UNAVAILABLE;
		}

		float value = 0.0f;
		for (uint8_t i = 0; i < 10; i++)
		{
			value += NL::AnalogInput::getAnalogVoltage(false);
		}
		value /= 33.0f; // 3.3V * 10

		if (value < threshold - antiFlickerThreshold)
		{
			brightness = 0.0f;
			return NL::LightSensor::Error::OK;
		}
		else if (value > threshold + antiFlickerThreshold)
		{
			value = (value - minAmbientBrightness) / (maxAmbientBrightness - minAmbientBrightness);
			if (value < 0.0f)
			{
				value = 0.0f;
			}
			else if (value > 1.0f)
			{
				value = 1.0f;
			}

			brightness = minLedBrightness + value * (maxLedBrightness - minLedBrightness);
			if (brightness < 0.0f)
			{
				brightness = 0.0f;
			}
			else if (brightness > 1.0f)
			{
				brightness = 1.0f;
			}
		}

		return NL::LightSensor::Error::OK;
	}

	// Auto on/off using BH1750
	else if (lightSensorMode == NL::LightSensor::LightSensorMode::AUTO_ON_OFF_BH1750)
	{
		if (!NL::BH1750::isInitialized())
		{
			brightness = 1.0f;
			return NL::LightSensor::Error::ERROR_BH1750_UNAVAILABLE;
		}

		float lux = 0.0f;
		if (NL::BH1750::getLux(lux) != NL::BH1750::Error::OK)
		{
			brightness = 0.0f;
			return NL::LightSensor::Error::ERROR_BH1750_UNAVAILABLE;
		}

		lux /= 54612.5f / 5.0f;
		if (lux > 1.0f)
		{
			lux = 1.0f;
		}

		if (lux > threshold + antiFlickerThreshold)
		{
			brightness = 0.0f;
		}
		else if (lux < threshold - antiFlickerThreshold)
		{
			brightness = 1.0f;
		}

		return NL::LightSensor::Error::OK;
	}
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

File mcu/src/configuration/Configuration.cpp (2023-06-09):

/**
 * @file Configuration.cpp
 * @author TheRealKasumi
 * @brief Contains the implementation of {@link NL::Configuration}.
 *
 * @copyright Copyright (c) 2023 TheRealKasumi
 *
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
 */
#include "configuration/Configuration.h"

bool NL::Configuration::initialized = false;
FS *NL::Configuration::fileSystem;
String NL::Configuration::fileName;
uint16_t NL::Configuration::configurationVersion;
size_t NL::Configuration::activeProfile;
std::vector<NL::Configuration::Profile> NL::Configuration::profiles;
NL::Configuration::WiFiConfig NL::Configuration::wifiConfig;
NL::Configuration::MotionSensorCalibration NL::Configuration::motionSensorCalibration;
NL::Configuration::AudioUnitConfig NL::Configuration::audioUnitConfig;

/**
 * @brief Initialize the configuration.
 * @param fileSystem pointer to a {@link FS}
 * @param fileName file name of the configuration file
 */
void NL::Configuration::begin(FS *fileSystem, const String fileName)
{
	// Initialize
	NL::Configuration::initialized = true;
	NL::Configuration::fileSystem = fileSystem;
	NL::Configuration::fileName = fileName;
	NL::Configuration::configurationVersion = CONFIGURATION_FILE_VERSION;

	// Load default settings
	NL::Configuration::loadDefaults();
}

/**
 * @brief Deinitialize the configuration.
 */
void NL::Configuration::end()
{
	NL::Configuration::initialized = false;
	NL::Configuration::profiles.clear();
}

/**
 * @brief Return if the configuration was initialized.
 * @return true when initialized
 * @return false when not initialized
 */
bool NL::Configuration::isInitialized()
{
	return NL::Configuration::initialized;
}

/**
 * @brief Get the number of profiles currently stored in the configuration.
 * @return number of profiles currently stored in the configuration
 */
size_t NL::Configuration::getProfileCount()
{
	return NL::Configuration::profiles.size();
}

/**
 * @brief Get the profile name by the profile index.
 * @param profileIndex index of the porfile
 * @param profileName reference to a string holding the name
 * @return OK when the profile name was read
 * @return ERROR_OUT_OF_BOUNDS when the profile index is invalid
 */
NL::Configuration::Error NL::Configuration::getProfileNameByIndex(const size_t profileIndex, String &profileName)
{
	if (profileIndex >= NL::Configuration::profiles.size())
	{
		return NL::Configuration::Error::ERROR_OUT_OF_BOUNDS;
	}

	profileName = NL::Configuration::profiles.at(profileIndex).name;
	return NL::Configuration::Error::OK;
}

/**
 * @brief Get a single profile from the configuration.
 * @param profileName name of the profile to get
 * @param profile reference to a variable holding the profile
 * @return OK when the profile was read
 * @return ERROR_PROFILE_NOT_FOUND when no profile with the given name was found
 */
NL::Configuration::Error NL::Configuration::getProfile(const String &profileName, NL::Configuration::Profile &profile)
{
	size_t profileIndex;
	const NL::Configuration::Error findError = NL::Configuration::getProfileIndexByName(profileName, profileIndex);
	if (findError != NL::Configuration::Error::OK)
	{
		return findError;
	}

	profile = NL::Configuration::profiles.at(profileIndex);
	return NL::Configuration::Error::OK;
}

/**
 * @brief Create a new profile with default settings.
 * @param profileName name of the new profile
 * @return OK when the new profile was created
 * @return ERROR_TOO_MANY_PROFILES when the profile limited is reached
 * @return ERROR_PROFILE_NAME_EXISTS when the profile name already exists
 */
NL::Configuration::Error NL::Configuration::createProfile(const String &profileName)
{
	if (NL::Configuration::profiles.size() + 1 > CONFIGURATION_MAX_PROFILES)
	{
		return NL::Configuration::Error::ERROR_TOO_MANY_PROFILES;
	}

	size_t profileIndex;
	const NL::Configuration::Error findError = NL::Configuration::getProfileIndexByName(profileName, profileIndex);
	if (findError == NL::Configuration::Error::OK)
	{
		return NL::Configuration::Error::ERROR_PROFILE_NAME_EXISTS;
	}

	NL::Configuration::Profile profile;
	profile.name = profileName;
	NL::Configuration::profiles.push_back(profile);
	NL::Configuration::loadProfileDefaults(NL::Configuration::profiles.size() - 1);
	return NL::Configuration::Error::OK;
}
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

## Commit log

2022-06-28 Initial commit.
    [Configuration.h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]
2023-03-31 Rework and extend logging.
    [Configuration.h]
2023-03-31 Update from internal dev.
    [Configuration.h]
2023-03-31 fix (rainbow) use trapezoidal wave form (#8)
    * fixed
    * Add newline at end of SystemConfiguration
    [SystemConfiguration.h, main.cpp]
2023-03-31 feat (switch) control TesLight by OEM ambient light (#13)
    * Add feature from internal repo.
    * Adjust endpoint paths.
    [Configuration.h]
2023-03-31 Remove comments (#15)
    [Configuration.h]
2023-03-31 fix various issues (#19)
    * Fix default LED count.
    * Lower threshold for automatic on/off
    * Fix bug for in memory binary file.
    * Adjustments to webapp
    * Adjustments to fading controlls.
    [Configuration.cpp, LedDriver.cpp, main.cpp]
2023-03-31 Adjust case size for voltage regulator. (#20)
    [mcu_case.stl]
2023-03-31 Fix 3D models.
    [mcu_case_all.stl, mcu_case_top.stl]
2023-03-31 Update to latest ESP32 core and do some secret stuff ;)
    [Configuration.h]
2023-03-31 Fix issue by lading all pixel into a buffer at once. (#24)
    [Configuration.cpp, main.cpp]
2023-03-31 Fix stability issues and improve server.
    [LedManager.cpp, LightSensor.cpp, SystemConfiguration.h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]
2023-03-31 Fix micros overflow issue. (#26)
    [main.cpp]
2023-03-31 Update part list to add fuse and fuse holder
2023-03-31 Implement power limit (#31)
    [Configuration.h]
2023-03-31 Add LED count setting to new UI. (#35)
2023-03-31 feat (hardware) migrate to new hardware version 2 (#41)
    * Adjust source code for new hardware version 2.
    * Update TesLight.postman_collection.json
    * Update TesLight.postman_collection.json
    [Configuration.h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]
2023-03-31 Update PCB and add heatsink to optinal parts.
    [BOM_PCB_TesLight_2.0.csv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]
2023-03-31 feat (HW 2.1) upgrade to hardware version 2.1 and implement related features (#45)
    * Push from internal dev branch
    * Bug fixes
    [BOM_PCB_TesLight_2.0.csv, BOM_PCB_TesLight_2.1.csv, BOM_PCB_TesLight_2.1_Header.csv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]
2023-03-31 Implement motion sensor to turn on/off TesLight, also updating BOM on the side. (#49)
    [BOM_PCB_TesLight_2.1.csv, BOM_PCB_TesLight_2.1_Header.csv, Configuration.h]
2023-03-31 Save motion sensor calibration (#51)
    [Configuration.h]
2023-03-31 Documentation: several enhancements (#65)
    * Documentation: install temperature sensors
    * Part List: Add 3 wire Symphony Stripes, #57
    * Part List: Add recommended length, #58
    * Documentation: How to position the board in the vehicle for correct acceleration directions of the sensor values, #59
    * Documentation: Part List: Add 3 wire cable, #61
    * Documentation: Planning: correct length of wire, #63
    * Documentation: Build: How to get the signal of the factory build footwell lights without any harm, #62
    * Documentation: Part List: Add 3 wire Symphony Stripes, polarity check #57
2023-03-31 feat (models) add 3D models for the mcu v2 (#42)
    * Add new case
    * Add new case and fan adapter
    * Add aio version and fix oopsi
    * Adjust docs for 3D printing.
    [TesLight_Board.stl, TesLight_Case.stl, TesLight_Case_AIO.stl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]
2023-03-31 Switch to json based Api (#69)
    * Switch to json based Api
    * Add newline at the end of file
    * Update for new swagger
    * Fix type
    * Fix timer issues
    * Make rendering and output frame rate independant.
    [Configuration.h, partition.csv]
2023-03-31 Corrected AIO Case Version (#73)
    * Delete TesLight_Case_AIO.stl
    Replace with new File
    * Updated TesLight Case AIO File
    Old AIO File had an bar where should be a hole. This error was only related to AIO-File.
    [TesLight_Case_AIO.stl]
2023-03-31 feat (api) api endpoint for ui settings (#76)
    * Add ui config endpoint and documentation
    * Update doc
    [Configuration.h]
2023-03-31 Add license
    [Configuration.h]
2023-03-31 doc: planning: adjust cable lengths (dashboard, front doors), according to user feedback, #74 (#83)
2023-03-31 feat (animation) add the new sparkele animator (#93)
    * Add sparkle animator from internal repo
    * Fixes
    * Fixes
    * 255
    * Fixes
    [Configuration.h]
2023-03-31 Adding system info endpoint and a lot of refactoring (#107)
    * Copy from internal
    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
    [Configuration.h]
2023-03-31 feat (fan) add multiple fan mode (#113)
    * Commit from internal
    * Fan mode validation
    [Configuration.h]
2023-03-31 feat(ui): add fan mode (#117)
    Closes: #114
2023-03-31 Add audio unit (#118)
    [Configuration.h]
2023-03-31 fix locale on Mac (#130)
    * Update compiler params
    * Update main.cpp
    [main.cpp]
2023-03-31 feat (audio) audio based sparkle (#126)
    * Implement bouncing
    * Push from internal
    * oopsi
    * Update
    * Small adjustments
    * small oopsi
    [Configuration.h]
2023-03-31 feat(ui): add color switch (#139)
2023-03-31 feat (driver) implement our own LED driver (#141)
    * Add from internal repo
    * Remove c-style casts
    * Fix stale LEDs
    * Minor stuff like comments
    * Update TesLight.cpp
    * Small fix
    [GradientAnimatorMotion.cpp, LedBuffer.cpp, LedDriver.cpp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]
2023-03-31 fix (bh1750) invert light sensor (#143)
    * Fix inverted light sensor
    * Add newline
    [BH1750.cpp, LightSensor.cpp]
2023-03-31 Implement profiles on MCU side (#144)
    [Configuration.h]
2023-03-31 fix(profiles): invalidate cache after profile switch (#150)
2023-03-31 feat: add new EQ effect (#164)
    * Add eq effect
    * feat(ui): add equalizer animation
    ---------
    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
    [DS18B20.cpp, GradientAnimatorMotion.cpp, LedManager.cpp]
2023-03-31 feat(motion): add auto motion sensor calibration to ui (#172)
2023-06-09 Renaming according to vote in Discord (#177)
    * Renaming according to vote in Discord
    * Update API documentation
    * Rename in mcu code
    * Rename model files
    * Update package tool
    * Documentation leftovers
    * PCB
    * Rename UI
    * DevOps: Renaming according to vote in Discord, #176
    * Fix 2.2 board
    * chore(pnpm): bump version to 8
    * chore(ui): update logo
    * docs: update app screenshot
    * tup -> nup
    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
    [BOM_NikoLight_Audio_Unit_1.0_2023-05-24.csv, BOM_PCB_NikoLight_1.0_2023-05-24.csv, BOM_PCB_NikoLight_2.0_2023-05-24.csv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]
2023-06-09 Make the project GPLv3 (#178)
    * Move to GPLv3
    * Oops
    * Another oopsi
    [Configuration.h]
2023-06-09 Update PCB files
    [BOM_NikoLight_Audio_Unit_1.0_2023-05-24.csv, BOM_NikoLight_Audio_Unit_1.0_2023-06-09.csv, BOM_PCB_NikoLight_2.2_2023-06-02.csv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]
2023-06-09 Add footwell lights
    [BOM_PCB_Footwell Light_2023-06-09.csv, PickAndPlace_PCB_Footwell Light_2023-06-09.csv]
2023-11-20 Update PCB to latest
    [BOM_PCB_NikoLight_2.2_2023-06-09.csv, BOM_PCB_NikoLight_2.2_2023-11-20.csv, PickAndPlace_PCB_NikoLight_2.2_2023-11-20.csv]
2023-12-26 Add xt30 and xt60 versions of 2.2 board
    [BOM_PCB_NikoLight_2.2_2023-11-20.csv, BOM_PCB_NikoLight_2.2_DCJ_2023-12-26.csv, BOM_PCB_NikoLight_2.2_XT30_2023-12-26.csv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]

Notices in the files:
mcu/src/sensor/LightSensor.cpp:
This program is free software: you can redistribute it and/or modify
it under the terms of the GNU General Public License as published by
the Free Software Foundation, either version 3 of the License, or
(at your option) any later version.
